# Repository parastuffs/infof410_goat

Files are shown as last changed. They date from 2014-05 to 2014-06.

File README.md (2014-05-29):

infof410_goat
=============

INFOF410 - Project GOAT

We should have a synchronization sent from the user and received by the
controller, but not the other way around.
Indeed, when the user crosses the first infrared, we want the controller
to take immediate action, hence the sync.
On the other hand, when the controller open the second door, the user
is not compelled to leave the SAS through it just yet. In this case,
we better have a boolean variable activated by the controller allowing
the user to get the frack out if he wishes.

>We want the environnement to be able to loose. So `E<> User.FAIL` should
be satisfied. But, with the cooperation of the controller, we
want `control: A[] not User.FAIL` to be satisfied as well, that is with 
the help of the controller, we
cannot loose the game.

The paragraph just above may be just bullshit. Indeed, the transition
to User.FAIL state is a controllable one. So no shit that with the help
of the controller, we will never take that transition!

The only solution here is to force the SAS model to send a sync signal
when the timer is out by adding a gard on SAS.handling_user state.

UppAal Tiga tips
----------------

* You can make several updates at the same time by seperating them with
commas.
* You can use logical operators in guards: || and &&.
* ~~We cannot take a transition with a sync signal if the corresponding
node is not in a state waiting for it.~~ So not true.

Current State
-------------

User:

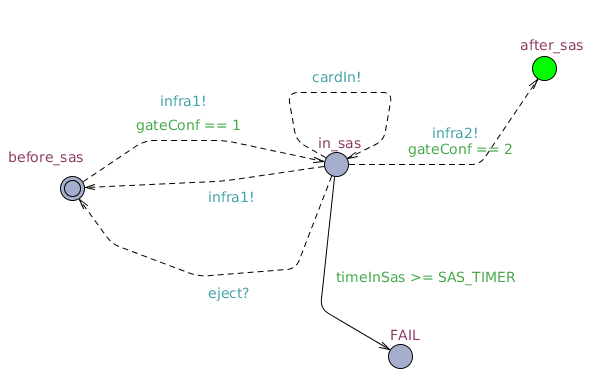
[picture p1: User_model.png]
User


SAS:

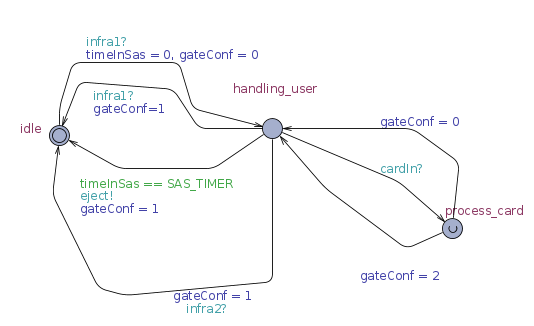
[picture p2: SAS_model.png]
SAS


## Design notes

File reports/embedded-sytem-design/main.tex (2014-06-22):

%%%%%%%%%%%%%%%%%%%%%%%%%%%%%%%%%%%%%%%%%
% Minimalist Book Title Page 
% LaTeX Template
% Version 1.0 (27/12/12)
%
% This template has been downloaded from:
% http://www.LaTeXTemplates.com
%
% Original author:
% Peter Wilson (herries.press@earthlink.net)
%
% License:
% CC BY-NC-SA 3.0 (http://creativecommons.org/licenses/by-nc-sa/3.0/)
% 
% Instructions for using this template:
% This title page compiles as is. If you wish to include this title page in 
% another document, you will need to copy everything before 
% \begin{document} into the preamble of your document. The title page is
% then included using \titleTH within your document.
%
%%%%%%%%%%%%%%%%%%%%%%%%%%%%%%%%%%%%%%%%%

%----------------------------------------------------------------------------------------
%	PACKAGES AND OTHER DOCUMENT CONFIGURATIONS
%----------------------------------------------------------------------------------------

%\title{Embedded Sytem Design: The GOAT}

\documentclass[10pt,a4paper]{article}

\usepackage[utf8]{inputenc}
\usepackage[T1]{fontenc}
\usepackage[svgnames]{xcolor} % Required to specify font color
\usepackage{mathpazo}
\usepackage{floatrow}
\usepackage{geometry}%réglages mise en page
\geometry{%
a4paper, % note : l'option a4paper tuait la marge supérieure.
body={170mm,250mm}, %
left=25mm,top=25mm,right=25mm, %
headheight=21mm,headsep=7mm,
marginparsep=4mm,
marginparwidth=20mm, %
footnotesep=50mm
}

\usepackage{graphicx}
\usepackage{float}
\usepackage{color}
\usepackage{amssymb}

%\usepackage[boxed]{algorithm2e}
\usepackage{array}
\usepackage{hyperref}
\usepackage{lscape}

%%% Pour colorier le code source C++/matlab
\usepackage{listings}
\usepackage{xcolor}
\usepackage[colorinlistoftodos]{todonotes}

\newcommand*{\course}{\fbox{INFO-F-410}} % Generic publisher logo

%----------------------------------------------------------------------------------------
%	TITLE PAGE
%----------------------------------------------------------------------------------------

\newcommand*{\titleTH}{\begingroup % Create the command for including the title page in the document
\raggedleft % Right-align all text
\vspace*{\baselineskip} % Whitespace at the top of the page

{\Large \textsc{Anthony Debruyn}}\\[0.01\textheight] % Author name
{\Large \textsc{Brian Delhaisse}}\\[0.01\textheight] % Author name
{\Large \textsc{Quentin Delhaye}}\\[0.167\textheight] % Author name

{\LARGE\bfseries Embedded Systems Design}\\[\baselineskip] % First part of the title, if it is unimportant consider making the font size smaller to accentuate the main title

{\textcolor{green}{\Huge The GOAT}}\\[\baselineskip] % Main title which draws the focus of the reader

{\Large \textit{The Gate Opener Actioned by Ticket}}\par % Tagline or further description

\vfill % Whitespace between the title block and the publisher

%\vspace*{30\baselineskip} % Whitespace at the bottom of the page

{\large \textsc{Gilles Geraerts} \course}\par % Publisher and logo

%\vspace*{5\baselineskip} % Whitespace at the bottom of the page
\endgroup}

%----------------------------------------------------------------------------------------
%	BLANK DOCUMENT
%----------------------------------------------------------------------------------------

%%%%%%%%%%%%%%%%%%%%%%%%%%%%%%%%%%%%%%%%%%%%%%%%%%%%%%%%%%%%%%%%%%%%%%%%
%%
%%    Environnement coloré pour écrire des codes.
%%
%%      Environnement :
%%       lstlisting
%%
%%      UTILISATION :
%%
%%         \lstset{language=c++}
%%         \lstset{commentstyle=\color{colComments}\textit}
%%         \begin{lstlisting}
%%             CODE
%%         \end{lstlisting}
%%
%%
%%%%%%%%%%%%%%%%%%%%%%%%%%%%%%%%%%%%%%%%%%%%%%%%%%%%%%%%%%%%%%%%%%%%%%%%

\definecolor{colKeys}{rgb}{0,0,1}  % couleurs des mots-clés propres au language
\definecolor{colIdentifier}{rgb}{0,0,0}  % couleurs des mots à identifier
\definecolor{colComments}{rgb}{0,0.6,0}  % couleurs des commentaires
\definecolor{colString}{rgb}{0.6,0.1,0.1}
%\lstset{}

%%%%%%%%%%%%%%%%%%%%%%%%%%%%%%%%%%%%%%%%%%%%%%%%%%%%%%%%%%%%%%%%%%%%%%%%%%%%%%%%%%%

\begin{document} 

\thispagestyle{empty}

\titleTH % This command includes the title page

\newpage

\tableofcontents
\newpage
%%%%%%%% Introduction %%%%%%%%%%
\section{Introduction}
For the course "Embedded Systems Design", we were asked to implement a system inspired from a subject in the course. We chose to use UppAal Tiga to design and create a strategy for a sas controlled by an Arduino Uno. This sas is composed of 2 doors actioned by servomotors. Infrared sensors are used to detect the person entering the sas. The opening of the second door of the sas is triggered by the scan of a valid card (rectangle with holes). Once someone is inside the sas, a timer is triggered to prevent the person to stay indefinitely inside. An alarm is activated once the timer is out.

%%%%%%%% The Model %%%%%%%%%%%%
\section{The Model}

In this section we will describe the physical properties that the system must satisfy, and make the link with the model.\\

First we want the system to always have at least one door closed. This is ensured by the 3 available configurations in the model: \emph{01} meaning door 1 open and door 2 closed, \emph{10} meaning the opposite, and \emph{00} meaning no door open.\\

Secondly, we want the back door (door 2) to open only if the user present one valid card having 2 holes in it.\\

The user also has to be ejected after some time if he does not show a valid card. This would prevent the user from staying indefinitely in the sas, blocking the other users. This is done by the timer in the model for the sas and the eject message. \\

The sas must detect the insertion of a card, even if it is not valid. This is modeled with the cardIn message in the UppAal Tiga systems.\\

An infrared sensor system has to detect the entry and exit of the user in order to react with the appropriate door configuration, and (de)activate the alarm. In the model, the infrared sensors are modeled with the infra1 \& infra2 signal.

The user must be able to escape the sas at any time. This is done with the infra1 sensor. If the user puts himself in front of the sensor, the front door opens to let him out.

The figures~\ref{userModel} and \ref{sasModel} represent these and the listings~\ref{globalDecl}, \ref{userDecl} and \ref{sasDecl} are their declarations.

A Typical run on the user side is as follows: The user begins in \texttt{before\_sas} and proceed into the sas by triggering the \texttt{infra1} signal if the first door is opened. He enters either with a valid or invalid card.
Once in the sas, he can present his card by triggering the \texttt{cardIn} signal.
At any moment, if the second door is opened, he can leave through it, or leave through the first door by triggering the signal \texttt{infra1}.
If the global clock \texttt{timeInSas} exceeds \texttt{SAS\_TIMER}, he can go to the \texttt{FAIL} state, and when receiving the \texttt{eject} signal, he will leave the sas.

A typical run on the sas side is as follows: From the \texttt{idle} state, uppon \texttt{infra1} signal, the sas resets the clock \texttt{timeInSas} and closes the first door. 
The sas is then handling a user. 
When a detects that a card is entered, it either opens the second door if the card is correct but keep both closed if the card is invalid.
If it receives the signal \texttt{infra1}, it means that the user is standing in front of the first sensor and wants to leave, hence the sas opens the first door.
Whenever the \texttt{timeInSas} clock reaches the \texttt{SAS\_TIMER}, the sas immediatly triggers the \texttt{eject} signal, willing to make the user leave the bloody sas.

\begin{figure}[!h]
	\centering
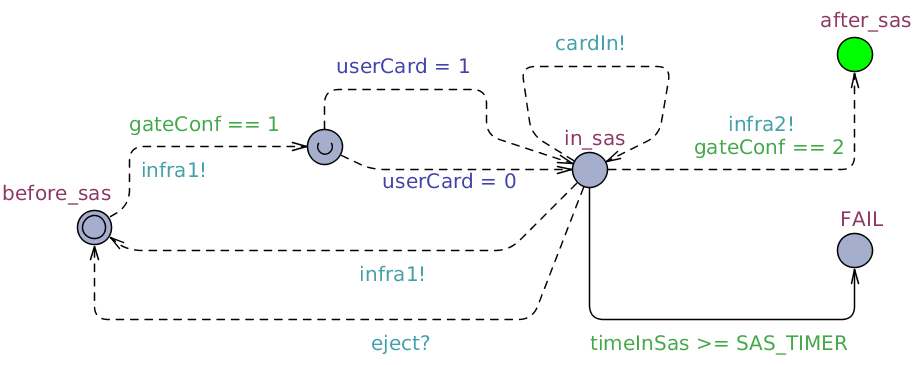
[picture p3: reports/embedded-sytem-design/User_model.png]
    
    \caption{The user model}
    \label{userModel}
\end{figure}

\begin{figure}[!h]
	\centering
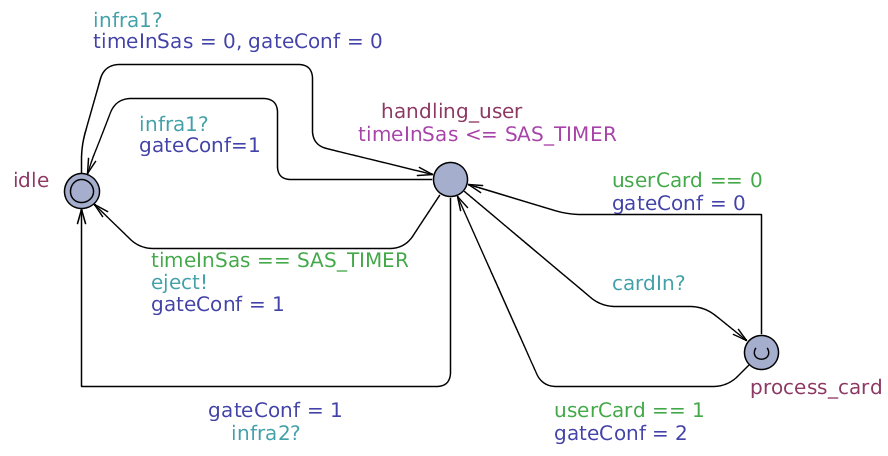
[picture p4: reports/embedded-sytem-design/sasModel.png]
    
    \caption{The sas model}
    \label{sasModel}
\end{figure}

\lstset{language=c++}
\lstset{commentstyle=\color{colComments}\textit,
%float=hbp,%
basicstyle=\ttfamily\small, %
identifierstyle=\color{colIdentifier}, %
keywordstyle=\color{colKeys}, %
stringstyle=\color{colString}, %
commentstyle=\color{colComments}, %
columns=flexible, %
tabsize=2, %
%frame=trBL, %
%frameround=tttt, %
extendedchars=true, %
showspaces=false, %
showstringspaces=false, %
numbers=left, %
numberstyle=\tiny, %
breaklines=true, %
breakautoindent=true, %
captionpos=b,%
%xrightmargin=-0.6cm, %
%xleftmargin=-0.6cm}
}
\begin{lstlisting}[caption=Global declarations of the systems., label=globalDecl]
chan infra1, infra2, cardIn, eject;
clock timeInSas;
const int SAS_TIMER = 10;
int gateConf = 1;
int userCard;
\end{lstlisting}
\begin{lstlisting}[caption=Declarations of the user model., label=userDecl]
clock x;
\end{lstlisting}
\begin{lstlisting}[caption=Declarations of the sas model., label=sasDecl]
clock x;
\end{lstlisting}

%%%%%%%%%%%%%%%%%%%%%%%%%%%%%%%%%
\section{The Strategy}
%%%%%%%%%%%%%%%%%%%%%%%%%%%%%%%%%
\subsection{Winning conditions}

\begin{description}
	%\item[\texttt{A<> not(User.FAIL)}] ~\\
    %	The user will never end up in FAIL.
        
    \item[\texttt{A[] not(User.in\_sas and User2.in\_sas)}] ~\\     
    Both users are never in the sas at the same time.
    Both models are exactly the same. The managment of a request token and a users queue will be implemented for the Formal Verification project.
    
    %\item[\texttt{A[] not deadlock}] ~\\
    
    \item[\texttt{E<> User.after\_sas}] ~\\
    	It is possible for the user to reach the other side of the sas. He won't succeed on every try, but if he wants to, he will.

    \item[\texttt{A[] not (User.FAIL)}] ~\\
    	We want to verify if the user will always avoid the FAIL state.
        At the instant \texttt{timeInSas} = \texttt{SAS\_TIMER} the system has two choice: either take \texttt{Sas.handling\_user} to \texttt{Sas.idle}, or \texttt{User.in\_sas} to \texttt{User.before\_sas}.
        The FAIL state is thus reachable and the test is expected to fail.
    
    \item[\texttt{control: A[] not(User.FAIL or User2.FAIL)}] ~\\
    Here, we play in a controller game.
    Having the controller collaboration, when the system is given the opportunity to either win or lose, well, it chooses to win.
    This condition is there to enforce the limited time in sas property.
    
    Please bear in mind here that we suppose that the \texttt{eject!} signal sent by the \texttt{Sas} has force of law.
    Hence, we know that when the controller is trying to comply with a winning condition, our physical system will be able to overcome the quite strong hypothesis made by the simulation tool stating that the environnement is always able to act faster than the controller.
    This liberty is represented by the controllable edge between \texttt{User.in\_sas} and \texttt{user.FAIL}.
\end{description}

We may also want to verify that if the user enters the sas with an invalid card, he will not make it to the other side, but if he has a valid card, he may.
This may be expressed as follows:
\begin{small}
\begin{verbatim}
	A[] ( ( (userCard == 0 && User.in_sas) imply A<> User.before_sas ) 
	&& ( (userCard == 1 && User.in_sas) imply E<> User.after_sas ) )
\end{verbatim}
\end{small}

Sadly, the syntax analyzer of UppAal does not accept a quantifier after the keyword \texttt{imply} and the above condition is not verifiable through its tools.\\

Finally, one could think that a suitable strategy for the sas to avoid the user to enter the \texttt{FAIL} state would simply be to never open the first door and let users in.
However, the model construction is such that the first door is always open when the sas is not occupied.
The only way to close the first door is for a user to enter the sas by triggering the \texttt{infra1} signal.

\subsection{Generated strategy}
The following strategy has been generated using a system with only one user for readability purposes.

\begin{verbatim}
Verifying property 5 at line 28
 -- Property is satisfied.
$v_gameInfoPlayInitial state:
( User.before_sas Sas.idle ) gateConf=1 
(timeInSas==User.x && User.x==Sas.x && Sas.x==0)

Strategy to avoid losing:

State: ( User.after_sas Sas.idle ) gateConf=1 
While you are in	true, wait.

State: ( User.before_sas Sas.idle ) gateConf=1 
While you are in	true, wait.

State: ( User.in_sas Sas.handling_user ) gateConf=2 
While you are in	(timeInSas<=10), wait.

State: ( User.in_sas Sas.process_card ) gateConf=0 
When you are in (timeInSas<=10), 
	take transition Sas.process_card->Sas.handling_user { 1, tau, gateConf := 2 }

State: ( User.in_sas Sas.process_card ) gateConf=2 
When you are in (timeInSas<=10), 
	take transition Sas.process_card->Sas.handling_user { 1, tau, gateConf := 2 }

State: ( User.in_sas Sas.handling_user ) gateConf=0 
While you are in	(timeInSas<=10), wait.
\end{verbatim}

The implementation code is presented in appendix~\ref{ap:code}. Each of those states were implemented using \texttt{if-then-else} statements decorated with all kind of computation that were hidden behind abstractions in the models.

\section{Physical Implementation}
\subsection{Parts list}
For our prototype, we used:
\begin{itemize}
	\item a microcontroller: Arduino UNO.
	\item 5 resistances (220$\Omega$).
    \item 3 leds (1red, 1yellow, 1green).
    \item 2 analog servo motors (FS5103B).
    \item 2 infrared proximity sensors short range.
    \item 2 photoresistors.
    \item 1 micro switch (DM3).
    \item 1 buzzer.
    \item 1 battery pack holder for 4x AA batteries + the 4xAA batteries.
    \item jump wires.
    \item 3 half-size protoboards.
\end{itemize}

\subsection{Electronic schematic}

\begin{figure}[!h]
	\centering
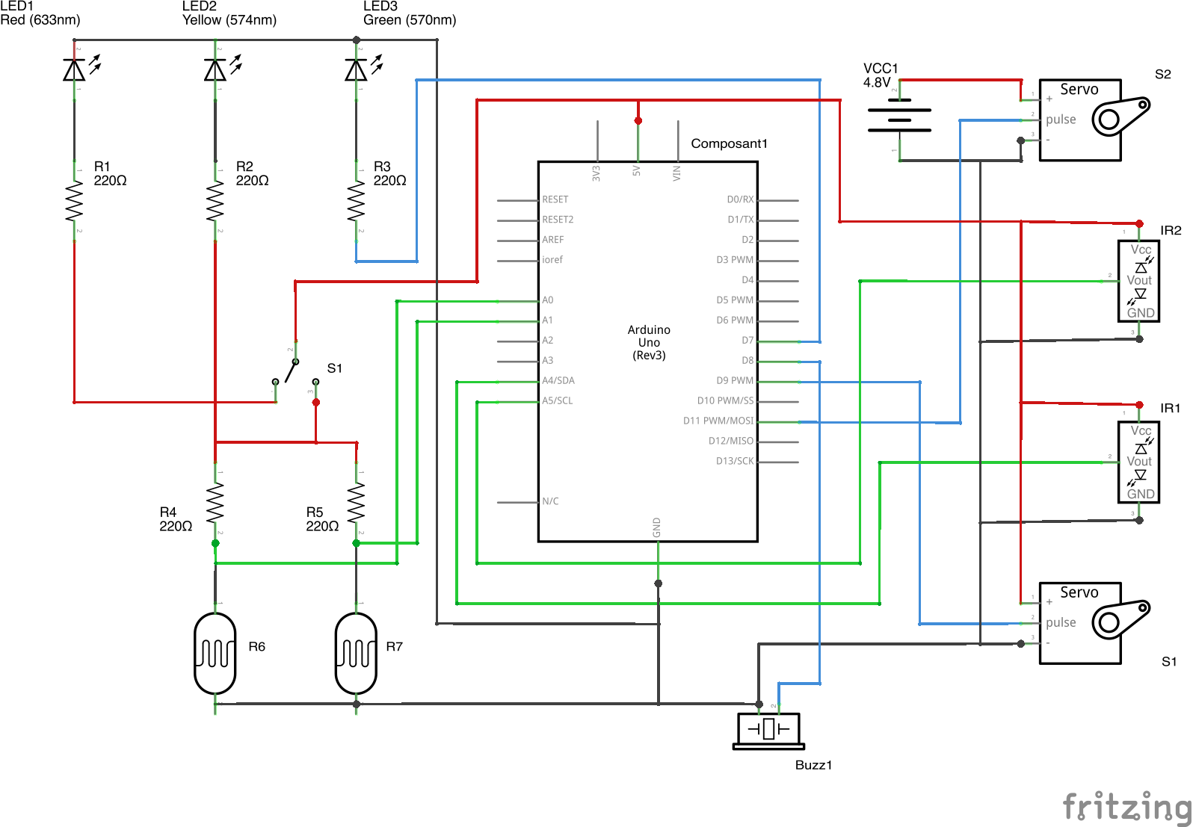
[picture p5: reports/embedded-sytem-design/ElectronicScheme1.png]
    
    \caption{Electrical diagram (modeled with Fritzing). Legend: \textcolor{red}{red wires} are connected to the positive terminal (of the arduino or the external battery), black wires are connected to the ground, \textcolor{green}{green wires} connect the electrical components to the analog input pins, and the \textcolor{blue}{blue wires} connect electrical components to digital output pins.}
    \label{elecScheme}
\end{figure}

Once the arduino is connected to a computer or to a battery, the positive terminal of the arduino supplies a tension of 5V to the electrical system, which can be seen on the figure \ref{elecScheme}. Because the servo motors drain a lot of current, another external battery was needed to supply enough current for both servo motors. Thus, an external battery has been connected to one of the servo. To avoid any other problems, we connected the ground of this one to the same ground as the arduino.

The resistors in front of each led are there so that the leds don't overdrive and burn out. The red led is always on until a card is inserted into the system. The card will push on the lever of the micro switch leading to the yellow led to turn on, and to the current to flow into the photoresistors.

The 2 resistors R4 and R5 with the photoresistors R6 and R7 form respectively a voltage divider. The voltage measured differs with the intensity of the light, that is, brighter the light is smaller the resistance of the photoresistor is. The resulting tension of those dividers are measured on the analog input pins A0 and A1 of the arduino. If the tension of each photoresistor is between a certain value, then the microcontroller is programmed to turn on the green led, and activate the 2nd servo motor (S2) in order to open the last door of the sas. 

If the user stays too long in the sas, the arduino can also trigger an alarm with the buzzer.

The two infrared proximity sensors IR1 and IR2 are there to detect if an object/person has entered or leaved the sas, they are respectively connected to the analog input pins A4 and A5. Based on the value measured, the microcontroller will activate one of the servo motors to close one of the gates, or to stop the buzzer.

\subsection{Electronic circuit}
On the real circuit, we used three breadboards because of the jump wires length that were too short. The two leftern protoboards on the figure \ref{circuit} are perpendicular to each other, in order for the card to be able to push on the lever of the micro switch, and for the photoresistors to be perpendicular to the card.

\begin{figure}[!h]
	\centering
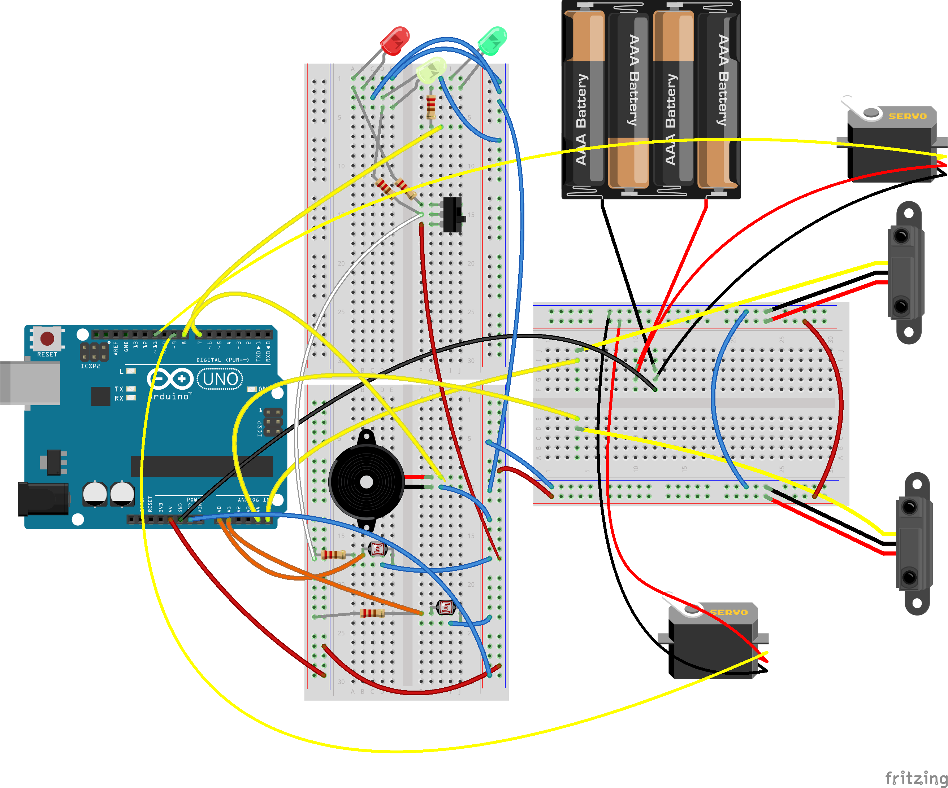
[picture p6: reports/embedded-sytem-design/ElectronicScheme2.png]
    
    \caption{The Circuit (modeled with Fritzing).}
    \label{circuit}
\end{figure}

\subsection{The structure}
The sas was build using Lego bricks, and the doors are in carton and connected to the servomotors with paperclips. We used cardboard to create some cards. A valid card has a hole in front of each photoresistor, so that the light can pass through it and be detected by the photoresistors. The final physical prototype can be found on the figure \ref{finalPrototype}.

%On figure \ref{inside}, the reader can view the inside of the sas. Here the first door is open, and the user is waiting.

\begin{figure}[!h]
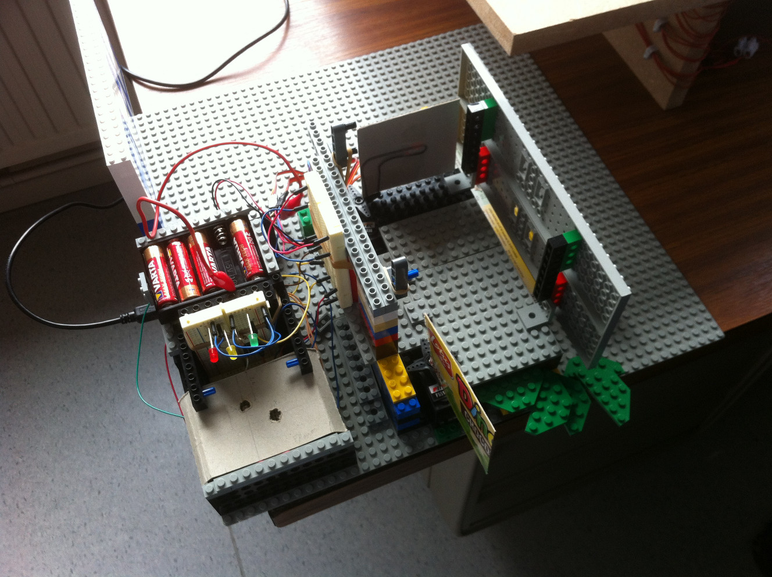
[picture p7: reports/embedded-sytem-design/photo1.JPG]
	
    \caption{Final prototype}
    \label{finalPrototype}
\end{figure}

\section{Future work}
Since we only use one infrared sensor at each door, we do not know the direction of the passing user. This causes problems in several situations:

\begin{itemize}
	\item If the user stays too long in the sas and the alarm activate, another user can enter in the sas. The alarm then stops. Now a third user can enter, and the front door closes. If one of the 2 users already in the sas puts something in front of the sensor, the front door closes as well. Thus any number of people enter the sas and go to the other side with one valid card.
    
    \item The same infrared problem occurs on the other side. If one user enters the sas from the back door when it is open, after the user has shown a valid card, the sas closes the second door. There are then 2 users in the sas, and the front door opens again, letting the second user escape.
	
\end{itemize}

These two problems could be resolved by using 2 more sensors to detect the direction of the passing user. Anoher solution could be to consider that the sas has only room for one person only.

%%%%%%%%%%%%%
\section{Conclusion}
%%%%%%%%%%%%%
This project has given us the opportunity to understand how we design embedded systems, by using specific tools to verify that a system respect some given proprieties. It was a rich experience to do the different parts of a project: the design of the model, the production of the code from the generated strategies, and the physical implementation so that we can see that our model really works in the real world.

\newpage

\appendix

\section{Arduino Code}\label{ap:code}
As mentionned above, the following code has been produced based on the generated strategies.\\

\lstset{language=c++}
\lstset{commentstyle=\color{colComments}\textit,
float=hbp,%
basicstyle=\ttfamily\small, %
identifierstyle=\color{colIdentifier}, %
keywordstyle=\color{colKeys}, %
stringstyle=\color{colString}, %
columns=flexible, %
tabsize=2, %
frame=trBL, %
frameround=tttt, %
extendedchars=true, %
showspaces=false, %
showstringspaces=false, %
numbers=left, %
numberstyle=\tiny, %
breaklines=true, %
breakautoindent=true, %
captionpos=b,%
xrightmargin=-0.6cm, %
xleftmargin=-0.6cm}
\begin{lstlisting}
#include <Servo.h> 

Servo servo1;  // create servo object to control a servo 
Servo servo2; 

int pos1;    // variable to store the servo position 
int pos2;

const int ledPin = 7;      // the number of the LED pin
const int buz = 8;
int buzCount = 0;

int gateConf;
unsigned long startTime;
const int SAS_TIMER = 5000;
boolean userIn;

#define but1 A4
#define but2 A5
#define infra1 (analogRead(A4) > 550)
int infra1Count;
#define infra2 (analogRead(A5) > 500)
int infra2Count;
#define cardIn (analogRead(A0) > 0 && analogRead(A1) > 0)

void setup() 
{ 
  pos1 = 0;//Opened
  pos2 = 90;//Closed
  servo1.attach(9);  // attaches the servo on pin 9 to the servo object 
  servo2.attach(11);
  Serial.begin(9600);
  servo1.write(pos1);
  delay(150);
  servo2.write(pos2);
  delay(150);
  
  // set the digital pin as output:
  pinMode(ledPin, OUTPUT);
  pinMode(buz, OUTPUT);
  
  gateConf = 1;
  userIn = false;
  infra1Count = 0;
  infra2Count = 0;
} 

void changeGateConf(int conf)
{
  gateConf = conf;
  switch (conf) {
    case 0:
      //from 1
      //Close gate 1
      for(pos1; pos1 < 90; pos1 += 1) {
        servo1.write(pos1);
        delay(15);
      }
      //gate 2 already closed
      break;
      
    case 1:
      //Open gate 1 : 0->90
      //Close gate 2 : 180->90
      for(pos2; pos2 > 90; pos2 -= 1) {
        servo2.write(pos2);
        delay(15);
      }
      for(pos1; pos1 > 0; pos1 -= 1) { 
        servo1.write(pos1);
        delay(15);
      }
      break;
      
    case 2:
      //gateConf = 2
      //Close gate 1: 90->0
      //Open gate 2: 0->90
      
      for(pos1; pos1 < 90; pos1 += 1) {  
        servo1.write(pos1);
        delay(15);
      }
      for(pos2; pos2 < 180; pos2  += 1) {
        servo2.write(pos2);
        delay(15);
      }
      break;
      
    default:
       break;
  }  
}

boolean processCard()
{
  int sensorValue = analogRead(A0);
  int sensorValue2 = analogRead(A1);
  if(sensorValue>200 && sensorValue<400 && sensorValue2>200 && sensorValue2<400)
    return true;
  else
    return false;
}

void alarm(boolean on)
{
  if(on) {
    int i;
    if(buzCount < 9) {
      for(i=0; i<10; i++) {
        digitalWrite(buz, HIGH);
        delay(3);//Shorter delay = higher pitch
        digitalWrite(buz, LOW);
        delay(3);
      }
      buzCount ++;
    } else {
      for(i=0; i<10; i++) {
        digitalWrite(buz, HIGH);
        delay(18);
        digitalWrite(buz, LOW);
        delay(18);
      }
      buzCount = 0;
    }
  }
}

void eject()
{
  digitalWrite(ledPin, LOW);
  changeGateConf(1);
  Serial.println("GET OUT. NOW");
  while(!infra1) {
    Serial.println("GET OUT. NOW");
    alarm(true);
  }
  while(infra1);
  alarm(false);
} 

void loop() 
{ 
  //infra1!
  if(infra1 && gateConf == 1 && !userIn) {
    userIn = true;
    Serial.print("userIn: ");
    Serial.println(userIn);
    gateConf = 0;
    changeGateConf(gateConf);
    startTime = millis();
  }
  
  if(infra2 && gateConf == 2) {
    gateConf = 1;
    userIn = false;
    digitalWrite(ledPin, LOW);
    changeGateConf(gateConf);
  }
  
  if(gateConf == 0 || gateConf == 2) {
    if((millis() - startTime) <= SAS_TIMER) {
      if(cardIn) {
        if(processCard()) {
          digitalWrite(ledPin, HIGH);
          gateConf = 2;
          changeGateConf(gateConf);
        }
        else
          digitalWrite(ledPin, LOW);
      }
      else
        digitalWrite(ledPin, LOW);
    }
    else {
      eject();
      userIn = false;
    }
  } 

  delay(50);   // delay in between reads for stability
} 
\end{lstlisting}

\end{document}

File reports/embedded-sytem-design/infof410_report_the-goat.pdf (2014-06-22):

ANTHONY DEBRUYN
BRIAN DELHAISSE
QUENTIN DELHAYE

# Embedded Systems Design

# The GOAT

## The Gate Opener Actioned by Ticket

### GILLES GERAERTS INFO-F-410

## Contents

1 Introduction | 3
2 The Model | 3
3 The Strategy | 4
4 Physical Implementation | 6
5 Future work | 8
6 Conclusion | 8
A Arduino Code | 9

## 1 Introduction

For the course "Embedded Systems Design", we were asked to implement a system inspired from a subject in the course. We chose to use UppAal Tiga to design and create a strategy for a sas controlled by an Arduino Uno. This sas is composed of 2 doors actioned by servomotors. Infrared sensors are used to detect the person entering the sas. The opening of the second door of the sas is triggered by the scan of a valid card (rectangle with holes). Once someone is inside the sas, a timer is triggered to prevent the person to stay indefinitely inside. An alarm is activated once the timer is out.

## 2 The Model

In this section we will describe the physical properties that the system must satisfy, and make the link with the model.

First we want the system to always have at least one door closed. This is ensured by the 3 available configurations in the model: 01 meaning door 1 open and door 2 closed, 10 meaning the opposite, and 00 meaning no door open.

Secondly, we want the back door (door 2) to open only if the user present one valid card having 2 holes in it.

The user also has to be ejected after some time if he does not show a valid card. This would prevent the user from staying indefinitely in the sas, blocking the other users. This is done by the timer in the model for the sas and the eject message.

The sas must detect the insertion of a card, even if it is not valid. This is modeled with the cardIn message in the UppAal Tiga systems.

An infrared sensor system has to detect the entry and exit of the user in order to react with the ap-propriate door configuration, and (de)activate the alarm. In the model, the infrared sensors are modeled with the infra1 & infra2 signal.
The user must be able to escape the sas at any time. This is done with the infra1 sensor. If the user puts himself in front of the sensor, the front door opens to let him out.
The figures 1 and 2 represent these and the listings 1, 2 and 3 are their declarations.
A Typical run on the user side is as follows: The user begins in before_sas and proceed into the sas by triggering the infra1 signal if the first door is opened. He enters either with a valid or invalid card. Once in the sas, he can present his card by triggering the cardIn signal. At any moment, if the second door is opened, he can leave through it, or leave through the first door by triggering the signal infra1. If the global clock timeInSas exceeds SAS_TIMER, he can go to the FAIL state, and when receiving the eject signal, he will leave the sas.
A typical run on the sas side is as follows: From the idle state, uppon infra1 signal, the sas resets the clock timeInSas and closes the first door. The sas is then handling a user. When a detects that a card is entered, it either opens the second door if the card is correct but keep both closed if the card is invalid. If it receives the signal infra1, it means that the user is standing in front of the first sensor and wants to leave, hence the sas opens the first door. Whenever the timeInSas clock reaches the SAS_TIMER, the sas immediatly triggers the eject signal, willing to make the user leave the bloody sas.
1 | chan infra1, infra2, cardIn, eject;
2 | clock timeInSas;
3 | const int SAS_TIMER = 10;
4 | int gateConf = 1;
5 | int userCard;
Listing 1: Global declarations of the systems.

1 clock x;
Listing 2: Declarations of the user model.

1 clock x;
Listing 3: Declarations of the sas model.

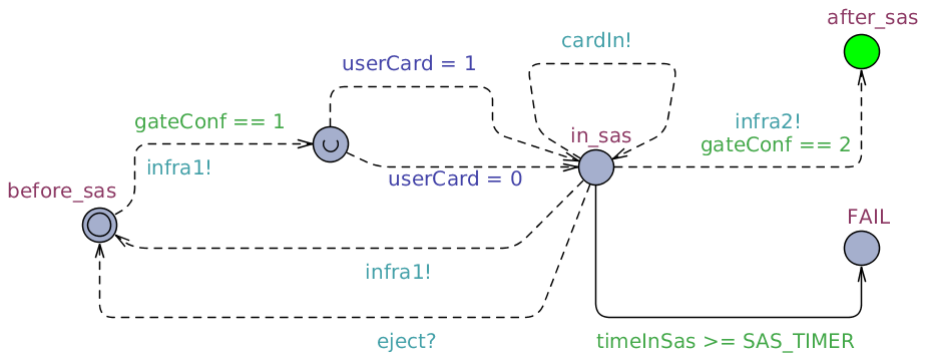
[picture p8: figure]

Figure 1: The user model

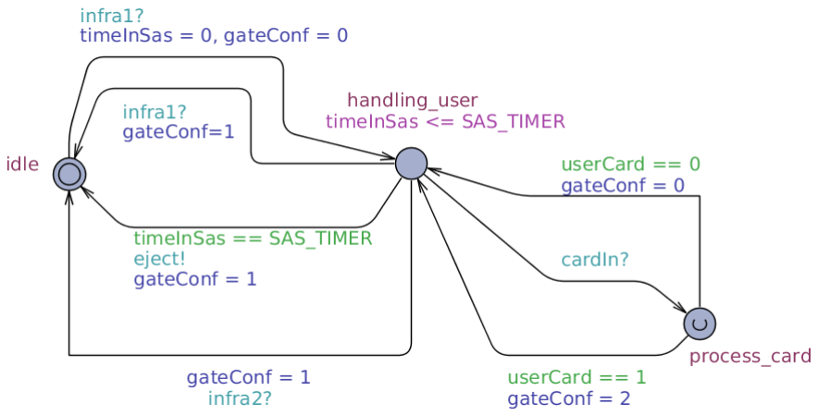
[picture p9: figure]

Figure 2: The sas model

## 3 The Strategy

### 3.1 Winning conditions

A[] not(User.in_sas and User2.in_sas)
Both users are never in the sas at the same time. Both models are exactly the same. The managment of a request token and a users queue will be implemented for the Formal Verification project.

E<> User.after_sas
It is possible for the user to reach the other side of the sas. He won’t succeed on every try, but if he wants to, he will.

A[] not (User.FAIL)
We want to verify if the user will always avoid the FAIL state. At the instant timeInSas = SAS_TIMER
the system has two choice: either take Sas.handling_user to Sas.idle, or User.in_sas to User.before_sas. The FAIL state is thus reachable and the test is expected to fail.

control: A[] not(User.FAIL or User2.FAIL)
Here, we play in a controller game. Having the controller collaboration, when the system is given the opportunity to either win or lose, well, it chooses to win. This condition is there to enforce the limited time in sas property.
Please bear in mind here that we suppose that the eject! signal sent by the Sas has force of law. Hence, we know that when the controller is trying to comply with a winning condition, our physical system will be able to overcome the quite strong hypothesis made by the simulation tool stating that the environnement is always able to act faster than the controller. This liberty is represented by the controllable edge between User.in_sas and user.FAIL.

We may also want to verify that if the user enters the sas with an invalid card, he will not make it to the other side, but if he has a valid card, he may. This may be expressed as follows:

A[] ( ( (userCard == 0 && User.in_sas) imply A<> User.before_sas )
&& ( (userCard == 1 && User.in_sas) imply E<> User.after_sas ) )

Sadly, the syntax analyzer of UppAal does not accept a quantifier after the keyword imply and the above condition is not verifiable through its tools.

Finally, one could think that a suitable strategy for the sas to avoid the user to enter the FAIL state would simply be to never open the first door and let users in. However, the model construction is such that the first door is always open when the sas is not occupied. The only way to close the first door is for a user to enter the sas by triggering the infra1 signal.

### 3.2 Generated strategy

The following strategy has been generated using a system with only one user for readability purposes.

Verifying property 5 at line 28
-- Property is satisfied.
$v_gameInfoPlayInitial state:
( User.before_sas Sas.idle ) gateConf=1 (timeInSas==User.x && User.x==Sas.x && Sas.x==0)

Strategy to avoid losing:

State: ( User.after_sas Sas.idle ) gateConf=1 While you are in true, wait.

State: ( User.before_sas Sas.idle ) gateConf=1 While you are in true, wait.

State: ( User.in_sas Sas.handling_user ) gateConf=2 While you are in (timeInSas<=10), wait.

State: ( User.in_sas Sas.process_card ) gateConf=0
When you are in (timeInSas<=10),
take transition Sas.process_card->Sas.handling_user { 1, tau, gateConf := 2 }

State: ( User.in_sas Sas.process_card ) gateConf=2
When you are in (timeInSas<=10),
take transition Sas.process_card->Sas.handling_user { 1, tau, gateConf := 2 }

State: ( User.in_sas Sas.handling_user ) gateConf=0
While you are in (timeInSas<=10), wait.

The implementation code is presented in appendix A. Each of those states were implemented using if-then-else statements decorated with all kind of computation that were hidden behind abstractions in the models.

## 4 Physical Implementation

### 4.1 Parts list

For our prototype, we used:

- a microcontroller: Arduino UNO.
- 5 resistances (220Ω).
- 3 leds (1red, 1yellow, 1green).
- 2 analog servo motors (FS5103B).
- 2 infrared proximity sensors short range.
- 2 photoresistors.
- 1 micro switch (DM3).
- 1 buzzer.
- 1 battery pack holder for 4x AA batteries + the 4xAA batteries.
- jump wires.
- 3 half-size protoboards.

### 4.2 Electronic schematic

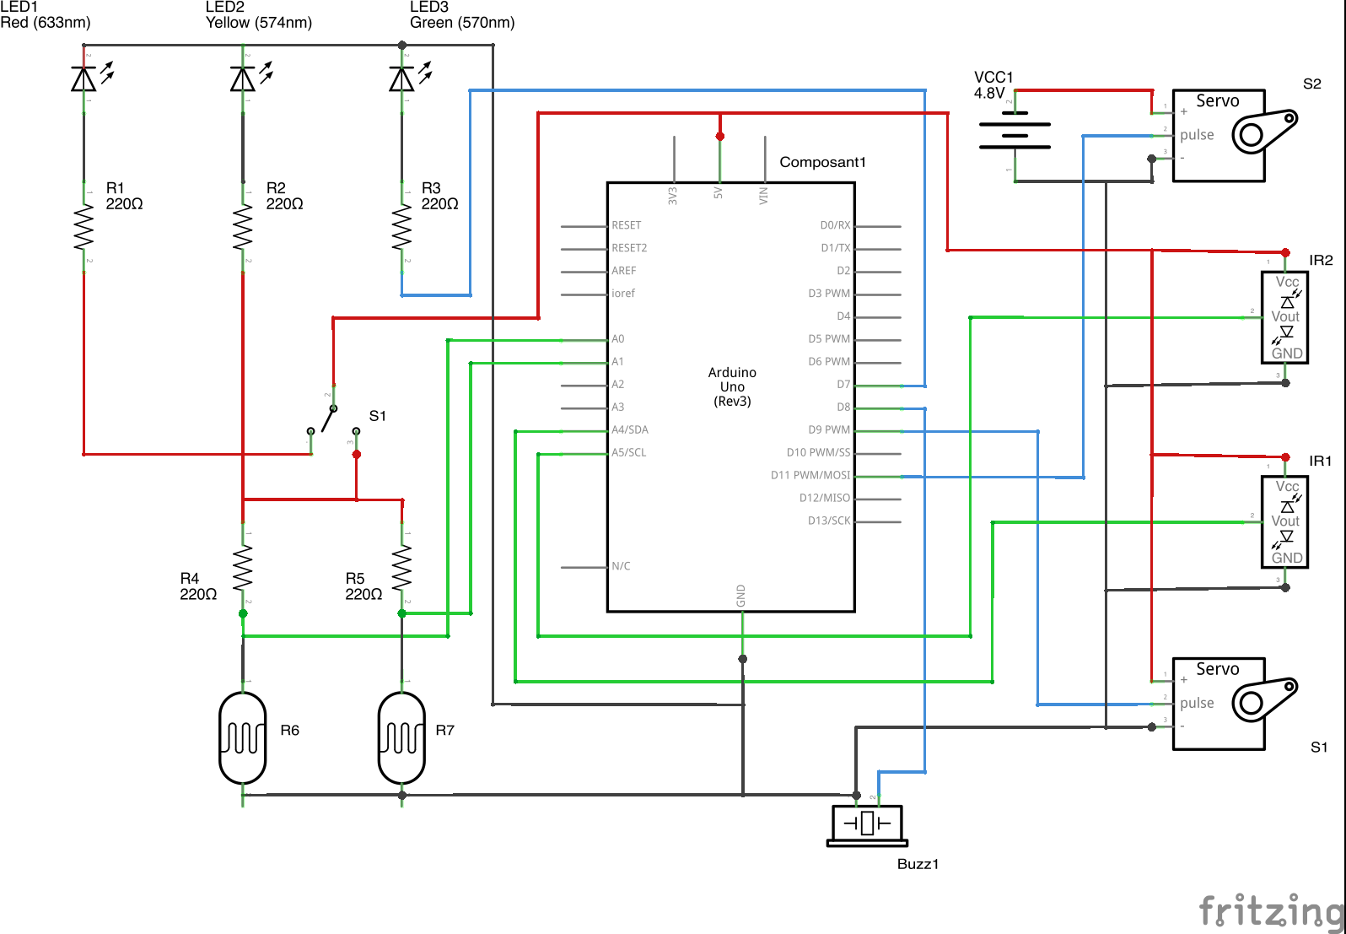
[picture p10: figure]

Figure 3: Electrical diagram (modeled with Fritzing). Legend: red wires are connected to the positive terminal (of the arduino or the external battery), black wires are connected to the ground, green wires connect the electrical components to the analog input pins, and the blue wires connect electrical components to digital output pins.

Once the arduino is connected to a computer or to a battery, the positive terminal of the arduino supplies a tension of 5V to the electrical system, which can be seen on the figure 3. Because the servo motors drain a lot of current, another external battery was needed to supply enough current for both servo motors. Thus, an external battery has been connected to one of the servo. To avoid any other problems, we connected the ground of this one to the same ground as the arduino.
The resistors in front of each led are there so that the leds don’t overdrive and burn out. The red led is always on until a card is inserted into the system. The card will push on the lever of the micro switch leading to the yellow led to turn on, and to the current to flow into the photoresistors.
The 2 resistors R4 and R5 with the photoresistors R6 and R7 form respectively a voltage divider. The voltage measured differs with the intensity of the light, that is, brighter the light is smaller the resistance of the photoresistor is. The resulting tension of those dividers are measured on the analog input pins A0 and A1 of the arduino. If the tension of each photoresistor is between a certain value, then the microcontroller is programmed to turn on the green led, and activate the 2nd servo motor (S2) in order to open the last door of the sas.
If the user stays too long in the sas, the arduino can also trigger an alarm with the buzzer.
The two infrared proximity sensors IR1 and IR2 are there to detect if an object/person has entered or leaved the sas, they are respectively connected to the analog input pins A4 and A5. Based on the value measured, the microcontroller will activate one of the servo motors to close one of the gates, or to stop the buzzer.

### 4.3 Electronic circuit

On the real circuit, we used three breadboards because of the jump wires length that were too short. The two leftern protoboards on the figure 4 are perpendicular to each other, in order for the card to be able to push on the lever of the micro switch, and for the photoresistors to be perpendicular to the card.


Figure 4: The Circuit (modeled with Fritzing).

### 4.4 The structure

The sas was build using Lego bricks, and the doors are in carton and connected to the servomotors with paperclips. We used cardboard to create some cards. A valid card has a hole in front of each photoresistor, so that the light can pass through it and be detected by the photoresistors. The final physical prototype can be found on the figure 5.


Figure 5: Final prototype

## 5 Future work

Since we only use one infrared sensor at each door, we do not know the direction of the passing user. This causes problems in several situations:

- If the user stays too long in the sas and the alarm activate, another user can enter in the sas. The alarm then stops. Now a third user can enter, and the front door closes. If one of the 2 users already in the sas puts something in front of the sensor, the front door closes as well. Thus any number of people enter the sas and go to the other side with one valid card.
- The same infrared problem occurs on the other side. If one user enters the sas from the back door when it is open, after the user has shown a valid card, the sas closes the second door. There are then 2 users in the sas, and the front door opens again, letting the second user escape.

These two problems could be resolved by using 2 more sensors to detect the direction of the passing user. Anoher solution could be to consider that the sas has only room for one person only.

## 6 Conclusion

This project has given us the opportunity to understand how we design embedded systems, by using specific tools to verify that a system respect some given proprieties. It was a rich experience to do the different parts of a project: the design of the model, the production of the code from the generated strategies, and the physical implementation so that we can see that our model really works in the real world.

## A Arduino Code

As mentionned above, the following code has been produced based on the generated strategies.
✞ | ☎

#include <Servo.h>

Servo servo1; // create servo object to control a servo Servo servo2;

6 | int pos1; | // variable to store the servo position
int pos2;
9 | const int ledPin = 7; | // the number of the LED pin
const int buz = 8;
int buzCount = 0;

int gateConf;
unsigned long startTime;
const int SAS_TIMER = 5000; boolean userIn;

#define but1 A4

#define but2 A5

#define infra1 (analogRead(A4) > 550) int infra1Count;

#define infra2 (analogRead(A5) > 500)

int infra2Count;
#define cardIn (analogRead(A0) > 0 && analogRead(A1) > 0)

void setup()

{
pos1 = 0;//Opened
pos2 = 90;//Closed
servo1.attach(9); // attaches the servo on pin 9 to the servo object servo2.attach(11);
Serial.begin(9600);
servo1.write(pos1);
delay(150);
servo2.write(pos2);
delay(150);

// set the digital pin as output: pinMode(ledPin, OUTPUT);
pinMode(buz, OUTPUT);

gateConf = 1;
userIn = false;
infra1Count = 0;
infra2Count = 0;

}

void changeGateConf(int conf)

{
gateConf = conf;
switch (conf) {
case 0:
//from 1
//Close gate 1
for(pos1; pos1 < 90; pos1 += 1) { servo1.write(pos1);
delay(15);

}
//gate 2 already closed
break;

61
62 | case 1:
63 | //Open gate 1 : 0->90
64 | //Close gate 2 : 180->90
65 | for(pos2; pos2 > 90; pos2 -= 1) {
66 | servo2.write(pos2);
67 | delay(15);
68 | }
69 | for(pos1; pos1 > 0; pos1 -= 1) {
70 | servo1.write(pos1);
71 | delay(15);
72 | }
73 | break;

74
75 | case 2:
76 | //gateConf = 2
77 | //Close gate 1: 90->0
78 | //Open gate 2: 0->90

79
80 | for(pos1; pos1 < 90; pos1 += 1) {
81 | servo1.write(pos1);
82 | delay(15);
83 | }
84 | for(pos2; pos2 < 180; pos2 += 1) {
85 | servo2.write(pos2);
86 | delay(15);
87 | }
88 | break;

89
90 | default:
91 | break;
92 | }
93 | }

94
95 | boolean processCard()
96 | {
97 | int sensorValue = analogRead(A0);
98 | int sensorValue2 = analogRead(A1);
99 | if(sensorValue>200 && sensorValue<400 && sensorValue2>200 && sensorValue2<400)
100 | return true;
101 | else
102 | return false;
103 | }

104
105 | void alarm(boolean on)
106 | {
107 | if(on) {
108 | int i;
109 | if(buzCount < 9) {
110 | for(i=0; i<10; i++) {
111 | digitalWrite(buz, HIGH);
112 | delay(3);//Shorter delay = higher pitch
113 | digitalWrite(buz, LOW);
114 | delay(3);
115 | }
116 | buzCount ++;
117 | } else {
118 | for(i=0; i<10; i++) {
119 | digitalWrite(buz, HIGH);
120 | delay(18);
121 | digitalWrite(buz, LOW);
122 | delay(18);
123 | }
124 | buzCount = 0;

125

}

126

}

127

}

128
129 | void eject()
130 | {
131 | digitalWrite (ledPin , LOW);
132 | changeGateConf(1);
133 | Serial .println ( "GET OUT . NOW ");
134 | while(!infra1) {
135 | Serial .println ( "GET OUT . NOW ");
136 | alarm (true);
137 | }
138 | while (infra1);
139 | alarm (false);
140 | }

141
142 | void loop()
143 | {
144 | //infra1 !
145 | if (infra1 && gateConf == 1 && !userIn) {
146 | userIn = true ;
147 | Serial .print ( "userIn : ");
148 | Serial .println (userIn);
149 | gateConf = 0;
150 | changeGateConf (gateConf);
151 | startTime = millis();
152 | }

153
154 | if (infra2 && gateConf == 2) {
155 | gateConf = 1;
156 | userIn = false ;
157 | digitalWrite (ledPin , LOW);
158 | changeGateConf (gateConf);
159 | }

160
161 | if (gateConf == 0 || gateConf == 2) {
162 | if((millis() - startTime) <= SAS_TIMER) {
163 | if (cardIn) {
164 | if (processCard()) {
165 | digitalWrite (ledPin , HIGH);
166 | gateConf = 2;
167 | changeGateConf (gateConf);
168 | }
169 | else
170 | digitalWrite (ledPin , LOW);
171 | }
172 | else
173 | digitalWrite (ledPin , LOW);
174 | }
175 | else {
176 | eject();
177 | userIn = false ;
178 | }
179 | }

180
181 | delay(50); // delay in between reads for stability
182 | }

✡✝

✆

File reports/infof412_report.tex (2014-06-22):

\documentclass[10pt,a4paper]{article}

\usepackage[utf8]{inputenc}
\usepackage[T1]{fontenc}
\usepackage[svgnames]{xcolor} % Required to specify font color
%\usepackage{mathpazo} %fancy font used by Anthony
\usepackage{floatrow}
\usepackage{geometry}%réglages mise en page
\geometry{%
a4paper, % note : l'option a4paper tuait la marge supérieure.
body={170mm,250mm}, %
left=25mm,top=25mm,right=25mm, %
headheight=21mm,headsep=7mm,
marginparsep=4mm,
marginparwidth=20mm, %
footnotesep=50mm
}

\usepackage{graphicx}
\usepackage{float}
\usepackage{color}
\usepackage{amssymb}

\usepackage{array}
\usepackage{hyperref}
\usepackage{lscape}

%%% Pour colorier le code source C++/matlab
\usepackage{listings}
\usepackage{xcolor}
\usepackage[colorinlistoftodos]{todonotes}

\definecolor{colKeys}{rgb}{0,0,1}  % couleurs des mots-clés propres au language
\definecolor{colIdentifier}{rgb}{0,0,0}  % couleurs des mots à identifier
\definecolor{colComments}{rgb}{0,0.6,0}  % couleurs des commentaires
\definecolor{colString}{rgb}{0.6,0.1,0.1}

\lstset{language=c++}
\lstset{commentstyle=\color{colComments}\textit, %
basicstyle=\ttfamily\small, %
identifierstyle=\color{colIdentifier}, %
keywordstyle=\color{colKeys}, %
stringstyle=\color{colString}, %
commentstyle=\color{colComments}, %
columns=flexible, %
tabsize=2, %
extendedchars=true, %
showspaces=false, %
showstringspaces=false, %
numbers=left, %
numberstyle=\tiny, %
breaklines=true, %
breakautoindent=true, %
captionpos=b,%
}

\title{INFO-F-412 Formal Verification of Computer Systems\\The GOAT-IE\\ \large{The Gate Opener Action by Ticket -- Improved Edition}}
\author{Quentin Delhaye}

%%%%%%%%%%%%%%%%%%%%%%%%%%%%%%%%%%%%%%%%%%%%%%%%%%%%%%%%%%%%%%%%%%%%%%%%%%%%%%%%%%%

\begin{document} 
\maketitle

%%%%%%%%%%%
\section{Introduction}
%%%%%%%%%%%
This project directly follows the Embedded Systems Design project.
In that project, entitled "\textit{The GOAT}", we modelised a sas with two doors.
When the sas was not occupied, the first door was open for anyone to enter.
Uppon user entering, the first door would close and a timer would begin.
In the given time, the user could present his card to be processed by the sas, or simply leave the sas by the first door.
If the card was accepted, the second door would open for the user to leave.
While doing all those actions, the timer clock would progress, and when reaching its limit, broadcast a signal to the user asking him to leave the sas by the first door, so that he would not stay in there forever.

In the present project, we want to improve the behavior of the sas by adding a queue for him to handle, in order to guarentee a fair sequence of users entering the sas.

%%%%%%%%%%%
\section{Improvement to the models}
%%%%%%%%%%%
The larger part of the models was not modified.
As we want to control the flow of users entering the sas, the new part involves the transition to and from \texttt{User.in\_sas}.

\begin{lstlisting}[caption=Global system declarations., label=lst:globalDecl]
chan infra1, infra2, cardIn, eject;
chan req;//Request channel
clock timeInSas;
const int SAS_TIMER = 10;
const int N_USERS = 2;
int reqID;
int turn;//The ID of the user whose it's turn.
int gateConf = 1;//Binary: g2g1 => 01 = gate 2 closed && gate 1 open, 00 both closed, 10 = gate 2 open && gate 1 closed.
int userCard;
\end{lstlisting}

\subsection{User}
In the user model, we add a new state \texttt{want\_in} that will be a pool in which the user goes if he, as the state name suggests, wants in.
The transition from \texttt{before\_sas} to \texttt{want\_in} triggers a signal \texttt{req} that will be followed in the sas model.

The second and last modification in this system is the new guard on the transition \texttt{want\_in} to \texttt{in\_sas}. Indeed, the user now has to wait for his turn, represented by the variable \texttt{turn} being set to his id.

The figure~\ref{fig:userModel} and listing~\ref{lst:userDecl} present this updated model. It is also to be noted that all users have a copy of the same model.

\begin{figure}[!h]
	\centering
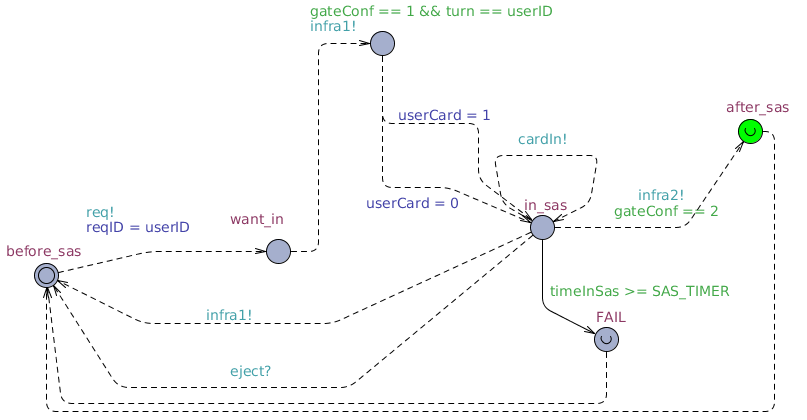
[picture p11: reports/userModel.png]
    
    \caption{New user model with request token.}
    \label{fig:userModel}
\end{figure}

\begin{lstlisting}[caption=Declarations of user model., label=lst:userDecl]
clock x;
const int userID = 1;
\end{lstlisting}

\subsection{Sas}
The first modification is the addition of new self-transitions on \texttt{idle} and \texttt{handling\_user} states for the reception of the signal \texttt{req}.
When receiving the signal, the sas receives the id of the corresponding user and appends it to the queue using the \texttt{addInQueue(int)} function.

When the user enters the sas, the sas model shifts the queue using \texttt{shiftQueue()} so that the next user in line is ready to enter as soon as the sas is available.

The figure~\ref{fig:sasModel} and listing~\ref{lst:sasDecl} present this updated model.

\begin{figure}[!h]
	\centering
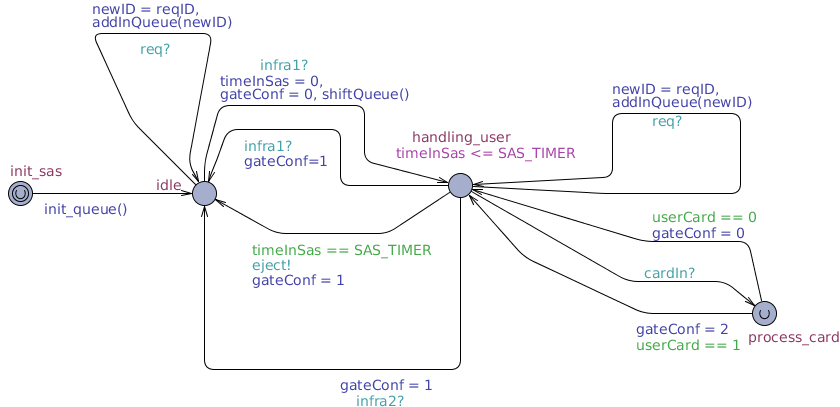
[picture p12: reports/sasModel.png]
    
    \caption{New sas model with queue handling.}
    \label{fig:sasModel}
\end{figure}

%%%%%%%%%%%
\section{Winning conditions}
%%%%%%%%%%%
Some winning condition have already been discussed in the Embedded Systems Design report.
For the new properties of the system, we may add the following expressions using \textsc{CTL}:
\begin{itemize}
	\item $\forall$\verb|[] (User.want_in |$\rightarrow \forall$ \verb|<> User.in_sas)| ~\\
		If the user want to enter the sas, he will enter the sas (liveness).
	\item $\forall$\verb|[] (User.before_sas |$\rightarrow \exists$ \verb|<> User.want_in| ~\\
		If the user is in idle mode, he will be able to request entering inside the sas (non-blocking).
	\item $\forall$\verb|[] not(User.in_sas and User2.in_sas)| ~\\
		Two users can not be in the sas at the same time (safety)\footnote{For the sake of completion, as this property was already presented in the linked project.}.
\end{itemize}

%%%%%%%%%%%
\section{Conclusion}
%%%%%%%%%%%
This project extends the one for Emebdded Systems Design by repairing one of its fault that was one user could monopolize the sas by leaving and entering it directly without giving other user a fair chance to access the said sas.
In a sense, we did enforce some sort of strict sequencing, but only to ensure a certain degree of fairness in the system. 
It is simply the modelisation of a real-life problem: poeple enter a queue to access a ressource that can only be used by one person for a certain amount of time.

If we want to take this project even one step further, we could make the sas two-way, instead of one.
In this improvement, both doors could be closed in idle mode and users could request its access from the first or the second door.
The modelisation would not differ that much, since we can use the same queue to store the requests, and the distribution mechanism of tokens would be sensibly the same.

\newpage
\appendix
%%%%%%%%%%%
\section{Sas declarations}
\begin{lstlisting}[caption=Sas model declarations., label=lst:sasDecl]
clock x;

int queue[N_USERS];
int newID;//Requester's ID

void init_queue()
{	
	int i;
	for(i = 0;i<N_USERS;++i) {
		queue[i] = 0;
	}
}

//Add a new id at the end of the queue
void addInQueue(int id) 
{
	int i;
	int set = 0;
	for(i=0;i<N_USERS && set==0;++i) {
		if(queue[i] == 0) {
			queue[i] = id;
			set = 1;
		}
	}
	turn = queue[0];//Update if necessary
}

//Shift each user one place forward in the queue
void shiftQueue()
{
	int i;
	for(i=0;i<N_USERS-1;++i) {
		queue[i] = queue[i+1];
	}
	queue[N_USERS-1] = 0;//Last place in the queue is available.
	turn = queue[0];//Update if necessary
}
\end{lstlisting}

\end{document}

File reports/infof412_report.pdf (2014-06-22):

## INFO-F-412 Formal Verification of Computer Systems The GOAT-IE

The Gate Opener Action by Ticket – Improved Edition

Quentin Delhaye

June 22, 2014

## 1 Introduction

This project directly follows the Embedded Systems Design project. In that project, entitled "The GOAT", we modelised a sas with two doors. When the sas was not occupied, the first door was open for anyone to enter. Uppon user entering, the first door would close and a timer would begin. In the given time, the user could present his card to be processed by the sas, or simply leave the sas by the first door. If the card was accepted, the second door would open for the user to leave. While doing all those actions, the timer clock would progress, and when reaching its limit, broadcast a signal to the user asking him to leave the sas by the first door, so that he would not stay in there forever.
In the present project, we want to improve the behavior of the sas by adding a queue for him to handle, in order to guarentee a fair sequence of users entering the sas.

## 2 Improvement to the models

The larger part of the models was not modified. As we want to control the flow of users entering the sas, the new part involves the transition to and from User.in_sas.

1 | chan infra1, infra2, cardIn, eject;
2 | chan req;//Request channel
3 | clock timeInSas;
4 | const int SAS_TIMER = 10;
5 | const int N_USERS = 2;
6 | int reqID;
7 | int turn;//The ID of the user whose it’s turn.
8 | int gateConf = 1;//Binary: g2g1 => 01 = gate 2 closed && gate 1 open, 00 both closed, 10 = gate
| 2 open && gate 1 closed.
9 | int userCard;
Listing 1: Global system declarations.

### 2.1 User

In the user model, we add a new state want_in that will be a pool in which the user goes if he, as the state name suggests, wants in. The transition from before_sas to want_in triggers a signal req that will be followed in the sas model.
The second and last modification in this system is the new guard on the transition want_in to in_sas. Indeed, the user now has to wait for his turn, represented by the variable turn being set to his id.
The figure 1 and listing 2 present this updated model. It is also to be noted that all users have a copy of the same model.
1 | clock x;
2 | const int userID = 1;
Listing 2: Declarations of user model.

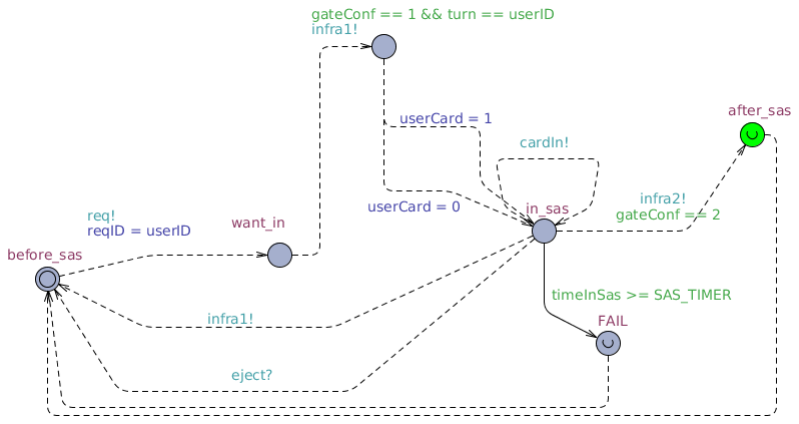
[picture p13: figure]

Figure 1: New user model with request token.

### 2.2 Sas

The first modification is the addition of new self-transitions on idle and handling_user states for the reception of the signal req. When receiving the signal, the sas receives the id of the corresponding user and appends it to the queue using the addInQueue(int) function.
When the user enters the sas, the sas model shifts the queue using shiftQueue() so that the next user in line is ready to enter as soon as the sas is available.
The figure 2 and listing 3 present this updated model.


Figure 2: New sas model with queue handling.

## 3 Winning conditions

Some winning condition have already been discussed in the Embedded Systems Design report. For the new properties of the system, we may add the following expressions using CTL:

- ∀[] (User.want_in → ∀ <> User.in_sas)
If the user want to enter the sas, he will enter the sas (liveness).
- ∀[] (User.before_sas → ∃ <> User.want_in
If the user is in idle mode, he will be able to request entering inside the sas (non-blocking).
- ∀[] not(User.in_sas and User2.in_sas)
Two users can not be in the sas at the same time (safety)¹

## 4 Conclusion

This project extends the one for Emebdded Systems Design by repairing one of its fault that was one user could monopolize the sas by leaving and entering it directly without giving other user a fair chance to access the said sas. In a sense, we did enforce some sort of strict sequencing, but only to ensure a certain degree of fairness in the system. It is simply the modelisation of a real-life problem: poeple enter a queue to access a ressource that can only be used by one person for a certain amount of time.
If we want to take this project even one step further, we could make the sas two-way, instead of one. In this improvement, both doors could be closed in idle mode and users could request its access from the first or the second door. The modelisation would not differ that much, since we can use the same queue to store the requests, and the distribution mechanism of tokens would be sensibly the same.

1For the sake of completion, as this property was already presented in the linked project.

## A Sas declarations

clock x;

int queue[N_USERS];
int newID;//Requester’s ID

void init_queue()

{
int i;
for(i = 0;i<N_USERS;++i) { queue[i] = 0;

}

}

//Add a new id at the end of the queue void addInQueue(int id)

{
int i;
int set = 0;
for(i=0;i<N_USERS && set==0;++i) { if(queue[i] == 0) {
queue[i] = id;
set = 1;

}

}
turn = queue[0];//Update if necessary

}

//Shift each user one place forward in the queue void shiftQueue()

{
int i;
for(i=0;i<N_USERS-1;++i) {
queue[i] = queue[i+1];

}
queue[N_USERS-1] = 0;//Last place in the queue is available. turn = queue[0];//Update if necessary

}
Listing 3: Sas model declarations.

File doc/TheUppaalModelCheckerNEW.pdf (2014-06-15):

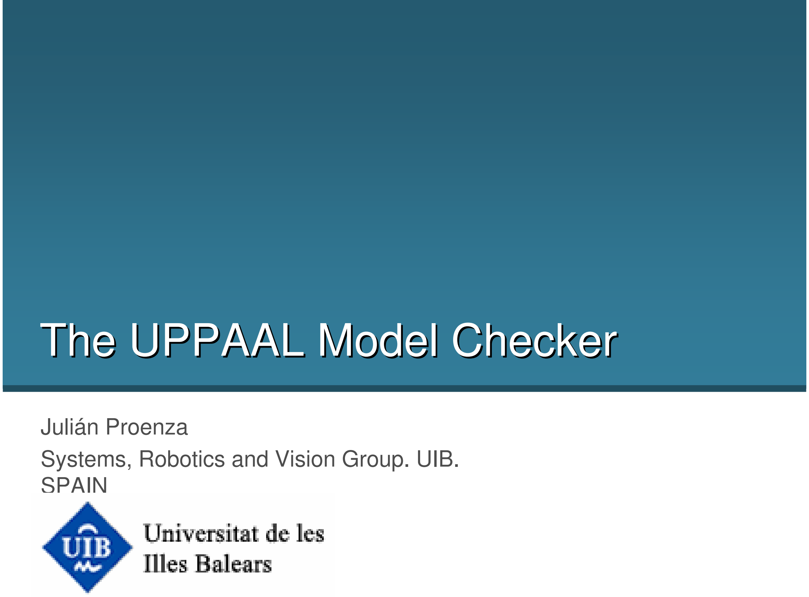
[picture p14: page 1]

# The UPPAAL Model Checker

Julián Proenza
Systems, Robotics and Vision Group. UIB. SPAIN

2

Julián Proenza. UIB. Oct 2008

# The aim of this presentation

### - Introduce the basic concepts of model checking from a practical perspective

### - Describe the basic features of the UPPAAL model

### checker

### - Use examples to illustrate the practical use of

### UPPAAL for the formal verification of systems

3

# Presentation Outline

### 1. The role of Model Checking in design validation

### 2. The UPPAAL Tool

### 1. Introduction 2. Modeling 3. Verification 4. A first example 5. Installation instructions

### 3. References

4

# Presentation Outline

### 1. The role of Model Checking in design validation

### 2. The UPPAAL Tool

### 1. Introduction 2. Modeling 3. Verification 4. A first example 5. Installation instructions

### 3. References

5

# The need for Design Validation

### - Hardware and software are widely used in applications

### where failure is unacceptable

### - Design Validation is necessary: ensuring design correctness at the earliest stage possible

- Traditional Techniques (rarely get exhaustive validation): – Simulation (on an abstraction or a model of the system) – Testing (on the actual product)
- Formal Methods (aimed at exhaustive validation) – Deductive Verification (costly, slow and only partially automatic) – Model Checking (for finite-state concurrent systems automatic)

6

# The Model Checking Technique

### - Use of Formal Methods has been considered for a long time a very desirable task for ensuring the correct design of a system

### - The complexity of these methods made them only

accessible to specialists (mathematicians). – Thus they were actually only used for very critical systems

### - Model Checking is the first technique that is truly

accessible for “normal” engineers – Enabling the use of formal verification in a wider spectrum of

applications (including VHDL systems) – Applicable to (finite-state concurrent systems) sequential

circuits, communication protocols, software…

7

# The 3 Steps of Model Checking

### 1. Build a model for the system, typically as a set of automata 2. Formalize the properties to be verified using expressions in a logic 3. Use the model checker (a tool) to generate the space of all possible

states and to exhaustively check whether the properties hold in each and everyone of the possible DYNAMIC BEHAVIOURS of the model

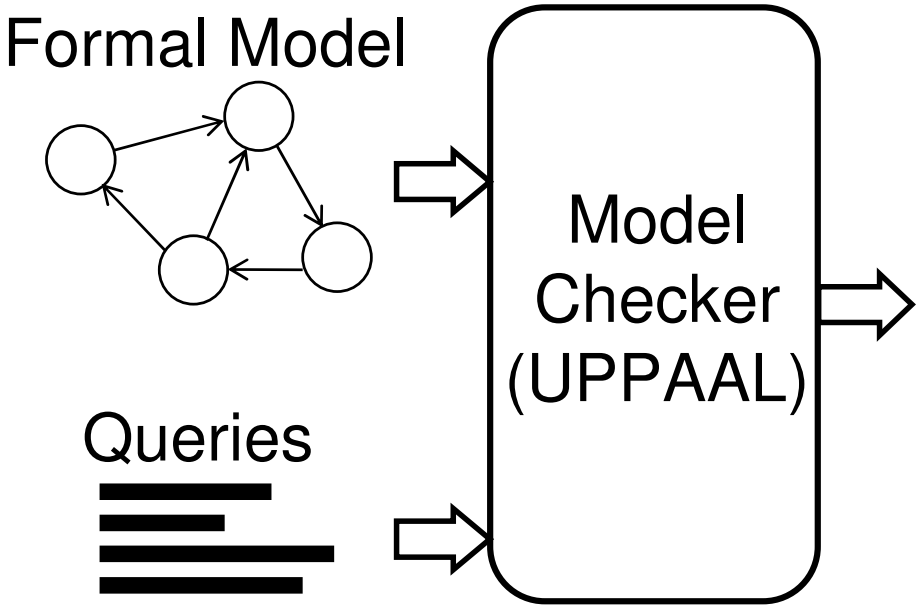
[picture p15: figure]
Model Checker (UPPAAL); Formal Model; Queries

### Yes

or

### No (counterexample)

### For each query

8

# Presentation Outline

### 1. The role of Model Checking in design validation

### 2. The UPPAAL Tool

### 1. Introduction 2. Modeling 3. Verification 4. A first example

9

# Introducing UPPAAL (v4.0.6)…

### - UPPAAL is a tool box for validation (via graphical simulation) and verification (via automatic model-

checking) of real-time systems.

- It consists of two main parts: – a Graphical User Interface (GUI) (executed on the users work

station) and – a model-checker engine (by default executed on the same

computer as the user interface, but can also run on a more powerful server)

### - It has been jointly developed by Uppsala University in Sweden and Aalborg University in Denmark

10

# An overview of the tool

Menu
Icons
Tabs

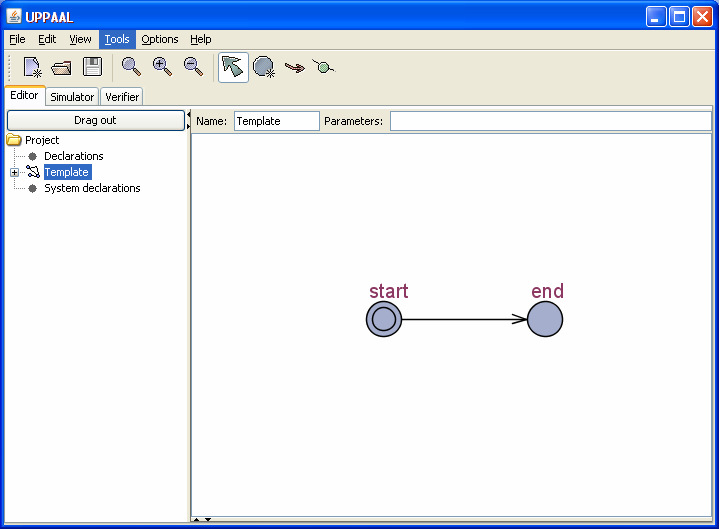
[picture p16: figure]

11

Julián Proenza. UIB. Oct 2008 An overview of the tool

# The Editor Window

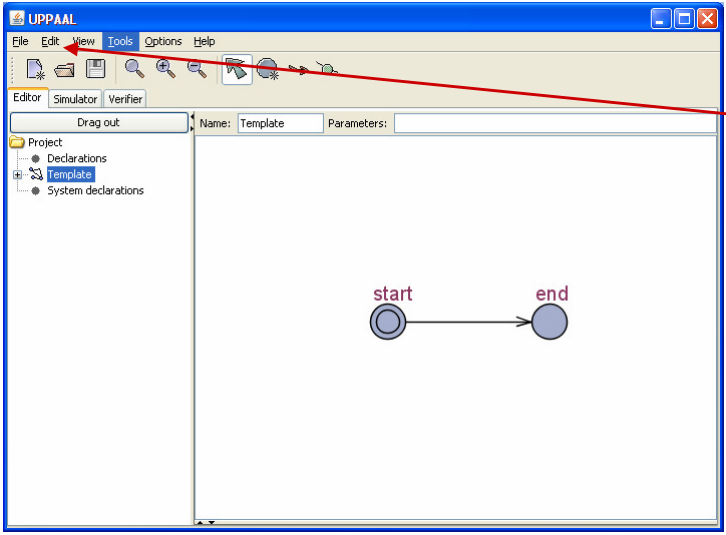
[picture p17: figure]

12

Julián Proenza. UIB. Oct 2008 An overview of the tool

# The Editor Window

With
“undo”!

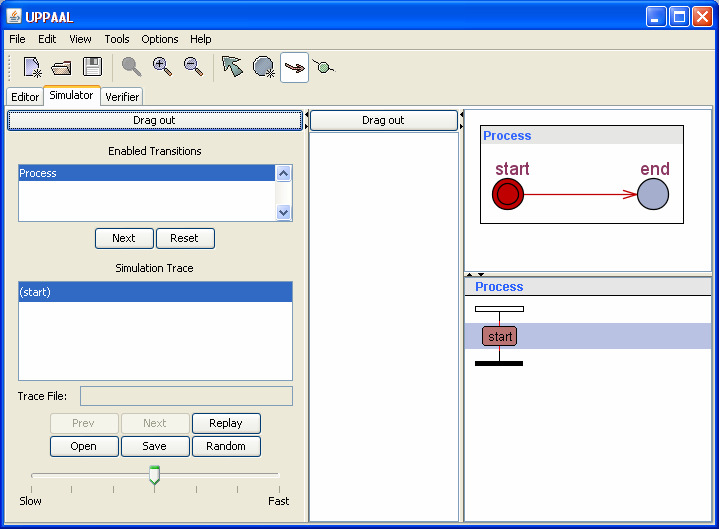
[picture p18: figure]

13

Julián Proenza. UIB. Oct 2008 An overview of the tool

# The Simulator Window (1)

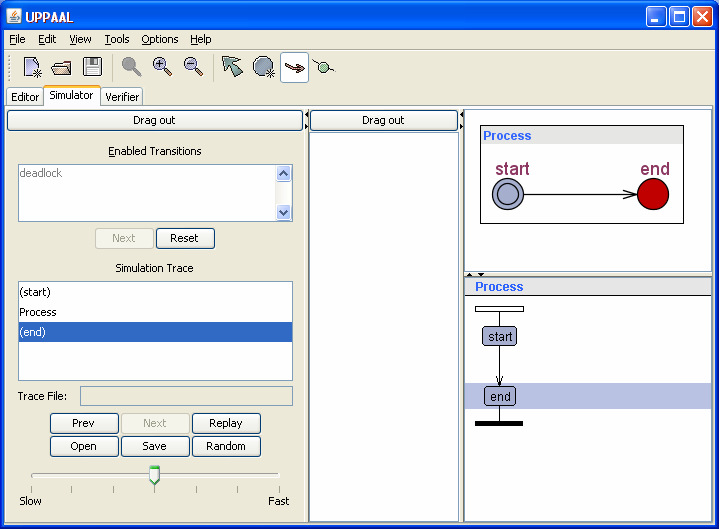
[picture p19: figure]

14

Julián Proenza. UIB. Oct 2008 An overview of the tool

# The Simulator Window (2)

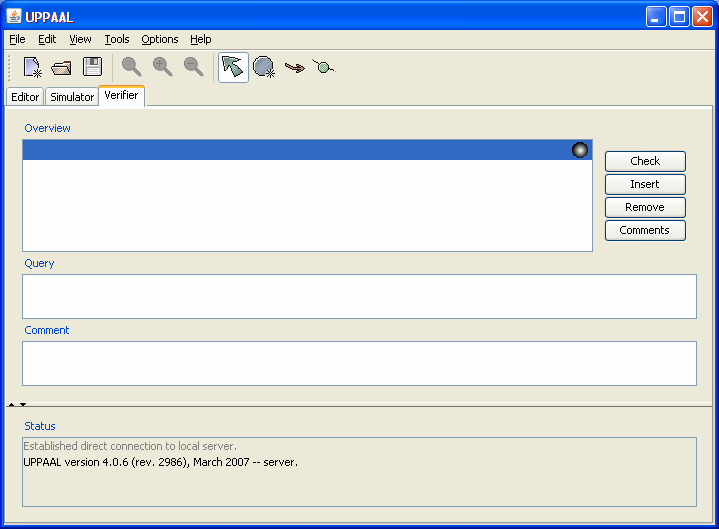
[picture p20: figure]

15

Julián Proenza. UIB. Oct 2008 An overview of the tool

# The Verifier Window (1)

16

Julián Proenza. UIB. Oct 2008 An overview of the tool

# The Verifier Window (2)

### 2. Edit

### 1. Click

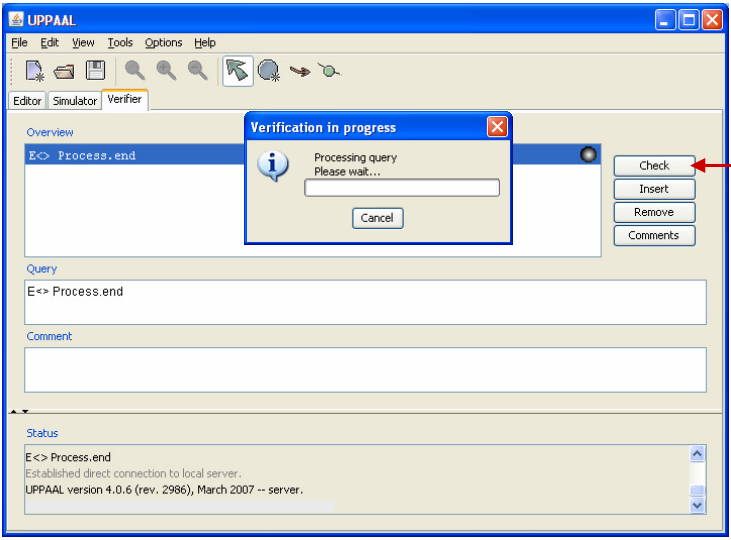
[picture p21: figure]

17

Julián Proenza. UIB. Oct 2008 An overview of the tool

# The Verifier Window (3)

Click

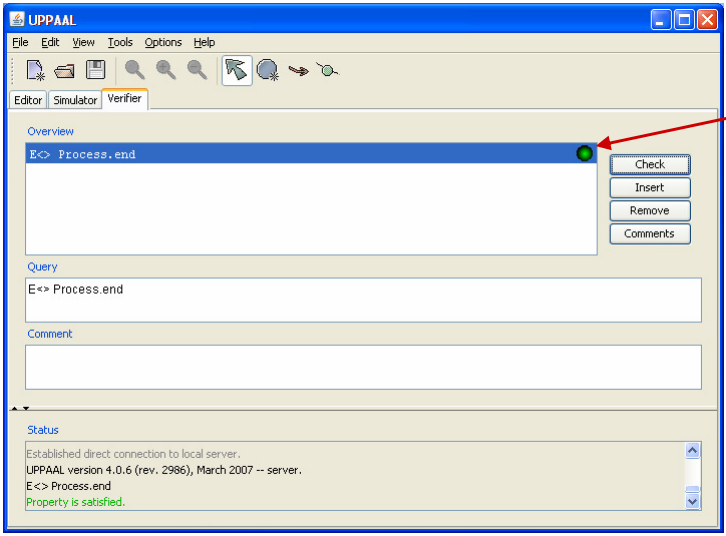
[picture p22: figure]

18

Julián Proenza. UIB. Oct 2008 An overview of the tool

# The Verifier Window (4)

Green
light

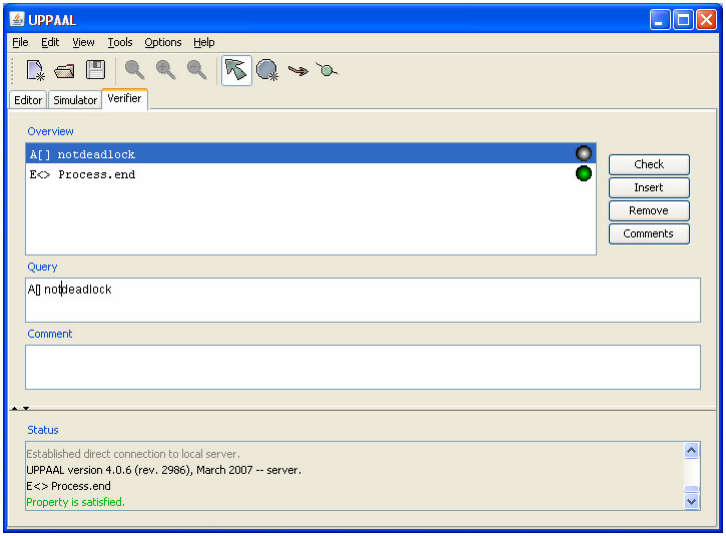
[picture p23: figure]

19

Julián Proenza. UIB. Oct 2008 An overview of the tool

# The Verifier Window (5)

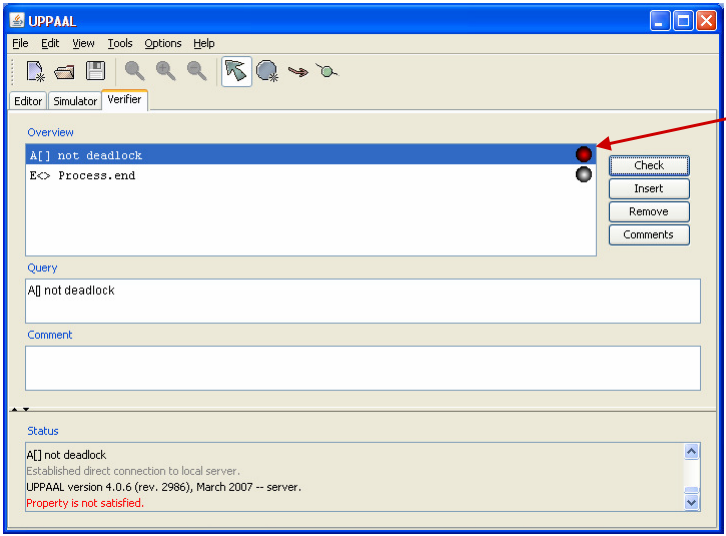
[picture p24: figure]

20

Julián Proenza. UIB. Oct 2008 An overview of the tool

# The Verifier Window (6)

Red
light

# The Verifier Window (7)

21

Julián Proenza. UIB. Oct 2008 An overview of the tool

Options
Diagnostic Trace
Some

# The Stored Trace (counterexample)

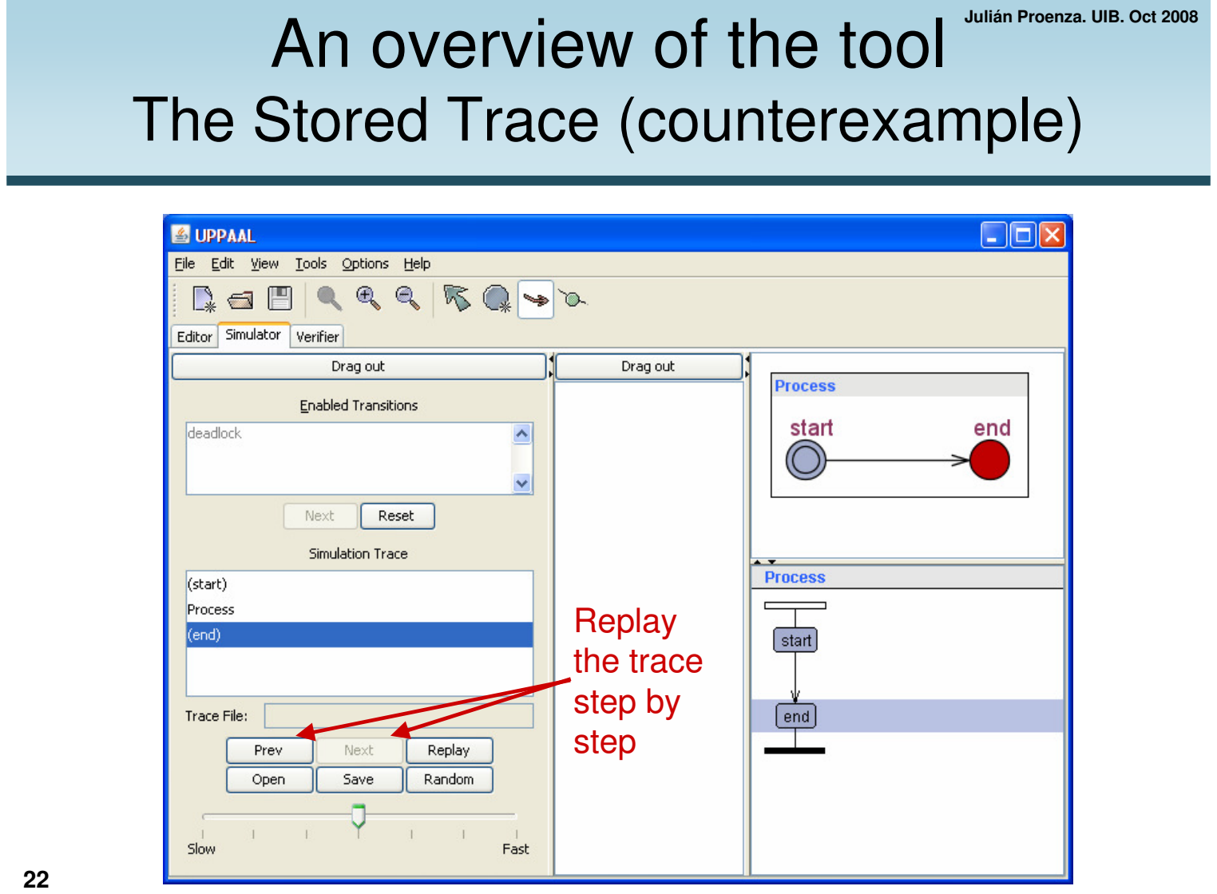
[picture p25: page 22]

22

Julián Proenza. UIB. Oct 2008 An overview of the tool

Replay
the trace
step by
step

23

# Presentation Outline

### 1. The role of Model Checking in design validation

### 2. The UPPAAL Tool

### 1. Introduction 2. Modeling 3. Verification 4. A first example 5. Installation instructions

### 3. References

24

# Modeling with UPPAAL

### - In UPPAAL, systems are modeled using timed-

automata, which are finite state machines with clocks. – Clocks are variables which can evaluate to a real number and

which can be defined in each automaton in order to measure the time progress. – All clocks evolve at the same pace in order to represent the

global progress of time. – The actual value of a clock can be either tested or reset (not

assigned).

### - Given that UPPAAL is specially designed for the

### verification of real-time systems, clocks are a

fundamental modeling and verification feature.

25

# Structure of an UPPAAL Model

### - An UPPAAL model is built as a set of concurrent

processes.

### - Each process is graphically designed as a timed-

automaton.

### - Since instantiations of the same automaton are frequently needed templates are used - A timed-automaton is represented as a graph which has locations as nodes and edges as arcs between

locations.
start | end

26

# Structure of an UPPAAL Model

### - An UPPAAL model is built as a set of concurrent

processes.

### - Each process is graphically designed as a timed-

automaton.

### - Since instantiations of the same automaton are frequently needed templates are used - A timed-automaton is represented as a graph which has locations as nodes and edges as arcs between

locations.

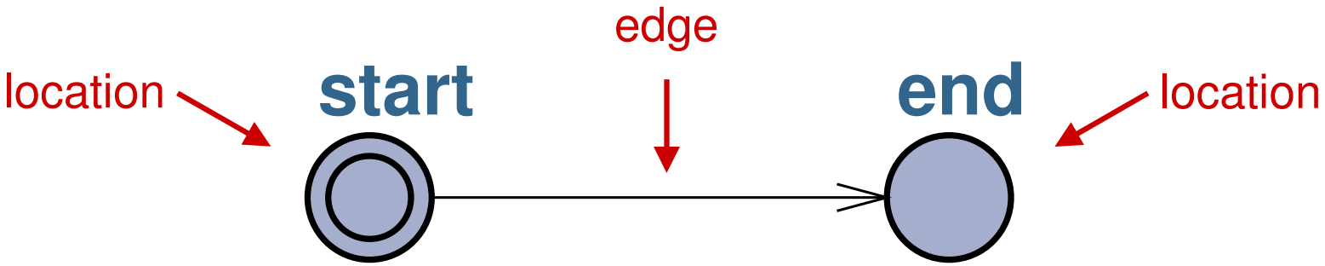
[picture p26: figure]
location; edge; start; end

27

# Labels in Edges

- Edges are annotated with guards, updates,

### synchronisations and selections

28

Julián Proenza. UIB. Oct 2008 Labels in Edges

# Guards

- Edges are annotated with guards, updates,

### synchronisations and selections

### - A guard is an expression which uses the variables and clocks of the model in order to indicate when the

transition is enabled, i.e. may be fired. – Note that several edges may be enabled at an specific time but

only one of them will be fired leading to different potential interleavings
start | end a==1

29

Julián Proenza. UIB. Oct 2008 Labels in Edges

# Updates

### - An update is an expression that is evaluated as soon as the corresponding edge is fired. This evaluation

changes the state of the system.

start | end a==1

b=0

30

Julián Proenza. UIB. Oct 2008 Labels in Edges

# Synchronisations

### - The synchronization is the basic mechanism used to coordinate the action of two or more processes. Models for instance the effect of messages

### - It causes two (or more) processes to take a transition at the same time. A channel (c) is declared, then one process will have an edged annotated with c! and the other(s) process(es) another edge annotated with c?

- Three different kinds of synchronizations: – Regular channel (leading to Binary Synchronization) – Urgent channel – Broadcast channel

31

Julián Proenza. UIB. Oct 2008 Labels in Edges

# Synchronisations: Regular Channel

- A regular channel is declared as, e.g., chan c. – When a process is in a location from which there is a transition

labelled with c! the only way for the transition to be enabled is that another process is in a location from which there is a transition labelled with c? and vice versa. – If at a specific instant there are several possible ways to have

a pair c! and c?, one of them is non-deterministically chosen during model checking. – The update expression on an edge synchronizing on c! is

executed before the update expression on an edge synchronizing on c?

start | end a==1 c!

b=0

start | end a==1 c?

b=0

32

Julián Proenza. UIB. Oct 2008 Labels in Edges

# Synchronisations: Urgent Channel

- An urgent channel is declared as urgent chan c. – Urgent channels are similar to regular channels, except that it

is not possible to delay in the source state if it is possible to trigger a synchronisation over an urgent channel. – This means no time can pass but they can interleave with

other transitions that require no time to pass. – Graphically they look like regular channels – Notice that clock guards are not allowed on edges

synchronising over urgent channels

start | end a==1 c!

b=0

start | end a==1 c?

b=0

33

Julián Proenza. UIB. Oct 2008 Labels in Edges

# Synchronisations: Broadcast Channel

- For a broadcast channel: broadcast chan c. – When one process is in a location from which there is a

transition labelled with c! and one or more processes are in locations from which there is a transition labelled with c? all these transitions are enabled. – However, if there are no processes in locations from which

there is a transition labelled with c?, the transition labelled with c! is enabled anyway. – Notice that clock guards are not allowed on edges receiving

on a broadcast channel. – The update on the emitting edge is executed first. The update

on the receiving edges are executed left-to-right in the order the processes are given in the system definition.

start | end a==1 c!

b=0

start | end a==1 c?

b=0

start | end a==1 c?

b=0

34

# Locations

### - Locations can have an optional name (as seen in

previous slides) – Names are useful to refer to the location during model checking

and when documenting the model

### - Locations can be of three different types (that can

be assigned by double-clicking on the location): – Initial – Urgent – Committed – Normal (all the rest)

35

Julián Proenza. UIB. Oct 2008 Location Types

# Initial

### - Each template must be properly initialized, meaning it must start in a specific location. Therefore, each template must have exactly one location marked as

initial.

### - Initial locations are identified with a double circle

start | end

Initial location

36

Julián Proenza. UIB. Oct 2008 Location Types

# Urgent

### - Urgent locations freeze time; i.e. time is not allowed to

pass when a process is in an urgent location. – The location must be left before time could pass – Other transitions may happen before, as long as they do not

require time to pass

### - Urgent locations are identified with a “U”

urgent location

### - Clock x will not increase as long as in loc1

start | loc1 | end x=0

37

Julián Proenza. UIB. Oct 2008 Location Types

# Committed

### - Committed locations also freeze time; i.e. time is not

allowed to pass when a process is in one of them. – When a model has one or more active committed locations, no

transitions other than those leaving said locations can be enabled. – Notice that if several processes are in a committed location at the

same time, then they will interleave. – Committed locations are useful for creating atomic sequences

### - Committed locations are identified with a “C”

### - Clock x will not increase as long as in loc1

start | loc1 | end x=0

38

# Invariants

- Both initial and normal locations can have invariants.

### - Invariants are conditions that must be fulfilled while the

automaton is in that location.
- They can be related to variables and clocks.
loc1 | end

a!=b

### start

loc1 | end

x<=T

start x=0 | x==T

39

# Invariants on clocks and time (1)

### - To better understand the role invariants on clocks

### play let us consider the following examples (proposed

at the UPPAAL tutorial) – The goal is to achieve a similar behaviour (stay in a location

until a condition on a clock holds and then leave the location) – First attempt without an invariant – Note that the “observer” allows the observation of the clock

value at different instants (clearer when completing the tutorial)

### loop x>=2

### reset!

idle | taken

x=0

### reset?

40

# Invariants on clocks and time (1)

### - To better understand the role invariants on clocks

### play let us consider the following examples (proposed

at the UPPAAL tutorial) – The goal is to achieve a similar behaviour (stay in a location

until a condition on a clock holds and then leave the location) – First attempt without an invariant – Note that the “observer” allows the observation of the clock

value at different instants (clearer when completing the tutorial)

loop | x>=2

time; Clock x

reset! | 2

41

# Invariants on clocks and time (2)

### - To better understand the role invariants on clocks

### play let us consider the following examples (proposed

at the UPPAAL tutorial) – The goal is to achieve a similar behaviour (stay in a location

until a condition on a clock holds and then leave the location) – Second attempt without an invariant

idle | taken

x=0

### reset? loop x==2

### reset!

42

# Invariants on clocks and time (2)

### - To better understand the role invariants on clocks

### play let us consider the following examples (proposed

at the UPPAAL tutorial) – The goal is to achieve a similar behaviour (stay in a location

until a condition on a clock holds and then leave the location) – Second attempt without an invariant

loop | x==2

time; Clock x

reset! | 2

43

# Invariants on clocks and time (3)

### - To better understand the role invariants on clocks

### play let us consider the following examples (proposed

at the UPPAAL tutorial) – The goal is to achieve a similar behaviour (stay in a location

until a condition on a clock holds and then leave the location) – Third attempt without an invariant (that will obviously have

the same problem!)

idle | taken

x=0

reset? loop x>=2,
x<=3

### reset!

time; Clock x

44

# Invariants on clocks and time (3)

### - To better understand the role invariants on clocks

### play let us consider the following examples (proposed

at the UPPAAL tutorial) – The goal is to achieve a similar behaviour (stay in a location

until a condition on a clock holds and then leave the location) – Third attempt without an invariant (that will obviously have

the same problem!)

loop | x>=2, x<=3
| reset!

45

# Invariants on clocks and time (4)

### - To better understand the role invariants on clocks

### play let us consider the following examples (proposed

at the UPPAAL tutorial) – The goal is to achieve a similar behaviour (stay in a location

until a condition on a clock holds and then leave the location) – Finally with an invariant

idle | taken

x=0

### reset? loop

x<=2

x==2

### reset!

46

# Invariants on clocks and time (4)

### - To better understand the role invariants on clocks

### play let us consider the following examples (proposed

at the UPPAAL tutorial) – The goal is to achieve a similar behaviour (stay in a location

until a condition on a clock holds and then leave the location) – Finally with an invariant

### loop

x<=2

x==2

time; Clock x

### reset! 2

47

# Invariants on clocks and time (5)

### - To better understand the role invariants on clocks

### play let us consider the following examples (proposed

at the UPPAAL tutorial) – The goal is to achieve a similar behaviour (stay in a location

until a condition on a clock holds and then leave the location) – A different behaviour with an invariant

idle | taken

x=0

### reset? loop

x<=3

x>=2

### reset!

48

# Invariants on clocks and time (5)

### - To better understand the role invariants on clocks

### play let us consider the following examples (proposed

at the UPPAAL tutorial) – The goal is to achieve a similar behaviour (stay in a location

until a condition on a clock holds and then leave the location) – A different behaviour with an invariant

### loop

x<=3

x>=2

time; Clock x

### reset! 2

49

# Invariants on clocks and time (6)

### - A final note: Semantically, urgent locations are

equivalent to: – adding an extra clock, x, that is reset on every incoming edge,

and – adding an invariant x <= 0 to the location.

loc1 | end

x<=0

### start x=0

start | loc1 | end

50

# Some modeling tricks

### - They are often necessary to actually reproduce the

behaviour of our system.

### - It is possible to encode “urgent transitions” with a guard on a variable, i.e. busy wait on a variable, by using urgent

channels. – Use a dummy automaton with one state looping with one transition

read!. The urgent transition will be x>0 read? for example.

### - There is no value passing though the channels but this

is easily encoded by a shared variable: – Define globally a variable x, and use it to write and read it. Notice

that it is not clean to do read! x:=3; and read? y:=x; but it is better to use a commit state: read? commit state and y:=x;.

51

# A recommendation on modeling

### - The state space grows very quickly with the model

complexity (state space explosion). It is necessary to: – Find the suitable level of abstraction for the model – Model only the features related to the properties to be verified – Also omit the features that are “obviously” correct

- More specifically: – The number of clocks has an important impact on the complexity – The use of committed locations can reduce significantly the state

space, but it can possibly take away relevant states. – The number of variables is also relevant and even more their

range. In particular, avoid unbounded loops on integers since the values will then span over the full range.

### - This is rather an “art” (so model checking is not so “perfect” as it initially looks but it helps to think)

52

# Presentation Outline

### 1. The role of Model Checking in design validation

### 2. The UPPAAL Tool

### 1. Introduction 2. Modeling 3. Verification 4. A first example 5. Installation instructions

### 3. References

53

# Verifying with UPPAAL

### - After using the simulator to ensure that the model

### behaves as the system we wanted to model (and sometimes also to detect some errors in the original

### design), the next phase is to check that the model verifies the properties

### - Then we need to know/decide what those properties

are… and formalize them! – Ex. from def. of consensus service: Consistency: All correct

servers agree on the same value and all decisions are final.

### - After that, we have to translate those properties into

### the UPPAAL query language (not one-to-one)

54

# The UPPAAL Query Language

### - The types of properties that can be directly checked

using the UPPAAL queries are quite simple.

### - UPPAAL designers have taken this approach, instead of allowing complex queries, in order to improve the

efficiency of the tool.

### - For this reason the verification of complex properties may need the checking of many different queries and even the addition to the model of specifically designed “testing automata”

55

# Types of Queries in UPPAAL

### - The specific types of properties that can be expressed

in the UPPAAL query language can be classified as: – Reachability properties. A specific condition holds

in some state of the model’s potential behaviours – Safety properties. A specific condition holds in all

### the states of an execution path – Liveness properties. A specific condition is

guaranteed to hold eventually (= at some moment) – Deadlock properties. A deadlock is possible or not

### in the model

56

# UPPAAL Reachability properties

### A specific condition holds in some state of the model’s potential behaviours

### - They are always expressed in the form:

### E<> p “Exists eventually p” meaning there is an execution path in which p eventually (in some state of the path) holds

57

# UPPAAL Reachability properties

### A specific condition holds in some state of the model’s potential behaviours

### - They are always expressed in the form:


### E<> p “Exists eventually p” meaning there is an execution path in which p eventually (in some state of the path) holds

Some
path

Some
state

# UPPAAL Safety properties

“Exists globally p”; “Always globally p”

A specific condition holds in all the states of an
execution path. Two possibilities:
meaning there is an execution
path in which p holds for all
the states of the path

For each (all) execution path
p holds for all the states of
the path

# UPPAAL Liveness properties

“q always leads to p”

A specific condition is guaranteed to hold eventually
(= at some moment). Two possibilities:
A<> p “Always eventually p”
For each (all) execution path
p holds for at least one state
of the path

Any path that “starts” with a
state in which q holds reaches
later a state in which p holds

60

# UPPAAL Deadlock properties

A deadlock is possible or not in the model.

### - A state is in a deadlock if it is impossible that the model evolves to a successor state neither by waiting some time nor by a transition between locations, i.e. there are no enabled transitions

- Two typical examples: – E<> deadlock = “Exists deadlock” – A[] not deadlock = “There is no deadlock”

### - Note that the word “deadlock” can be used inside any expression formalizing a specific property

61

# Some remarks on verification

### - When using model checking for verifying a system, it is usually studied whether there is any deadlock in the

model or not – A deadlock can be evidence of a design error but not necessarily – It could be enough to verify that deadlock only happens when

expected. E.g. :
A[] deadlock imply (cont==max and autom.end)
- Even using abstraction the state space may explode.
There are verification options that may help. – If some options are enabled, the output of the verifier might be

that property is "maybe satisfied".The verifier cannot determine the truth value of the property due to the approximations used.

62

# Presentation Outline

### 1. The role of Model Checking in design validation

### 2. The UPPAAL Tool

### 1. Introduction 2. Modeling 3. Verification 4. A first example 5. Installation instructions

### 3. References

63

# A simple example from the tutorial (1)

- A mutex algorithm. Specification.
Process 1 | Process 2
req1=1; | req2=1;
turn=2; | turn=1;
while(turn!=1 && req2!=0); | while(turn!=2 && req1!=0);
//critical section | //critical section
job1(); | job2();
req1=0; | req2=0;

64

# A simple example from the tutorial (2)

- A mutex algorithm. Modeling with UPPAAL.

Process 1; idle:; req1=1;; want:; turn=2;; wait:; while(turn!=1 && req2!=0);; //critical section; job1();; wait; idle; want; req2==0; turn==me; req1=0; turn=(me==1? 2:1); req1=1

//and return to idle
req1=0;

A[] not(P1.CS and P2.CS)
E<> P1.CS

65

# Presentation Outline

### 1. The role of Model Checking in design validation

### 2. The UPPAAL Tool

### 1. Introduction 2. Modeling 3. Verification 4. A first example 5. Installation instructions

### 3. References

66

# Installation Instructions

- Make sure you have the Java version 5 installed. – E.g.: www.java.com/es/download/manual.jsp

### - Go to the UPPAAL page: www.uppaal.com

### - Click on the download tag and then on the link Uppaal 4.0 (current official release)

### - Fill the license agreement form. Click on “Register & Download”

### - Unzip files

### - To run UPPAAL double-click the file uppaal.jar

67

# Presentation Outline

### 1. The role of Model Checking in design validation

### 2. The UPPAAL Tool

### 1. Introduction 2. Modeling 3. Verification 4. A first example 5. Installation instructions

### 3. References

68

# References

### Some used to create this presentation and some useful for further reading

- UPPAAL (all available at www.uppaal.com) – Uppaal2k: Small Tutorial. 16 October 2002 – G. Behrmann, A. David, and K. G. Larsen. A Tutorial on Uppaal – UPPAAL Online Help
- Model Checking – C. Baier and J.-P. Katoen. Principles of Model Checking. MIT

Press. 2008. – E.M. Clarke, O. Grumberg and D.A. Peled. Model Checking.

The MIT Press. 2000.

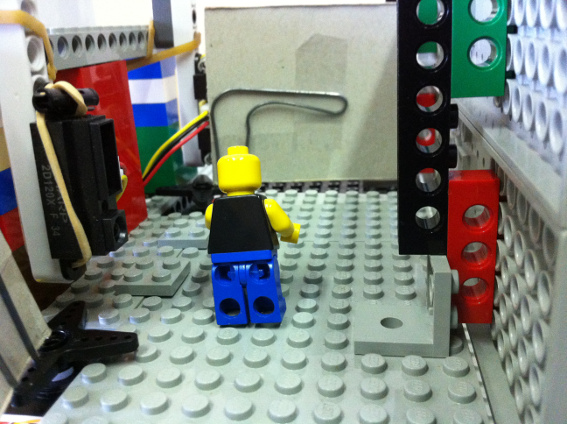
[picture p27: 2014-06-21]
reports/embedded-sytem-design/photo.JPG

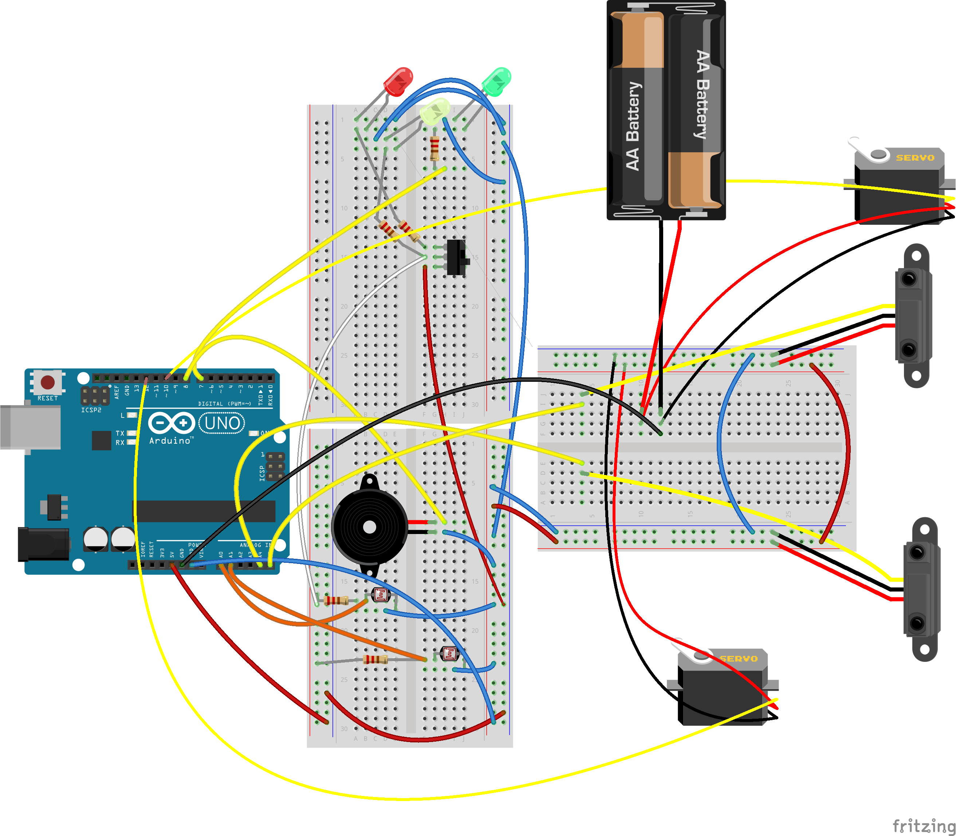
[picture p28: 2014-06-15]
goat2_bb.png

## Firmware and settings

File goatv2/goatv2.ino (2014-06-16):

// Sweep
// by BARRAGAN <http://barraganstudio.com> 
// This example code is in the public domain.

//unsigned long time = millis(); return elapsed milliseconds since startup.


#include <Servo.h> 

Servo myservo;  // create servo object to control a servo 
// a maximum of eight servo objects can be created
Servo servo2; 

int pos;    // variable to store the servo position 
int pos2;

const int ledPin =  7;      // the number of the LED pin
const int buz = 8;
int buzCount = 0;

int gateConf;
unsigned long startTime;
const int SAS_TIMER = 5000;
boolean userIn;
boolean userLeaving;//User is leaving, in infra1

#define but1 A4
#define but2 A5
#define infra1 (analogRead(A4) > 550)
int infra1Count;
#define infra2 (analogRead(A5) > 500)
int infra2Count;
#define cardIn (analogRead(A0) > 0 && analogRead(A1) > 0)

void setup() 
{ 
  pos = 0;//Opened
  pos2 = 90;//Closed
  myservo.attach(9);  // attaches the servo on pin 9 to the servo object 
  servo2.attach(11);
  Serial.begin(9600);
  myservo.write(pos);
  delay(150);
  servo2.write(pos2);
  delay(150);
  
  // set the digital pin as output:
  pinMode(ledPin, OUTPUT);
  pinMode(buz, OUTPUT);
  
  gateConf = 1;
  userIn = false;
  userLeaving = false;
  infra1Count = 0;
  infra2Count = 0;
} 

void changeGateConf(int conf)
{
  gateConf = conf;
  switch (conf) {
    case 0:
      //from 1
      //Close gate 1
      for(pos; pos < 90; pos += 1)  // goes from 0 degrees to 180 degrees 
      {                                  // in steps of 1 degree 
        //Serial.print("Closing gate1: ");
        //Serial.println(pos);
        myservo.write(pos);              // tell servo to go to position in variable 'pos' 
        delay(15);                       // waits 15ms for the servo to reach the position 
      }
      //We could simply write myservo.write(90), but the rotation would be too quick.
      //gate 2 already closed
      break;
     case 1:
       Serial.println("Close gate2 and open gate1");
    
      //Open gate 1 : 0->90
      //Close gate 2 : 180->90
      for(pos2; pos2 > 90; pos2 -= 1)  // goes from 0 degrees to 180 degrees 
      {      // in steps of 1 degree 
        //Serial.print("Closing gate2: ");
        //Serial.println(pos2);
        servo2.write(pos2);              // tell servo to go to position in variable 'pos' 
        delay(15);                       // waits 15ms for the servo to reach the position 
      }
      for(pos; pos > 0; pos -= 1)  // goes from 0 degrees to 180 degrees 
      {                                  // in steps of 1 degree
        //Serial.print("Opening gate1: ");
        //Serial.println(pos);
        myservo.write(pos);              // tell servo to go to position in variable 'pos' 
        delay(15);                       // waits 15ms for the servo to reach the position 
      }
      break;
     case 2:
       //gateConf = 2
      //Close gate 1: 90->0
      //Open gate 2: 0->90
      Serial.println("Close gate1 and open gate2");
      
      
      for(pos; pos < 90; pos += 1)  // goes from 0 degrees to 180 degrees 
      {                                  // in steps of 1 degree 
        //Serial.print("Closing gate1: ");
        //Serial.println(pos);
        myservo.write(pos);              // tell servo to go to position in variable 'pos' 
        delay(15);                       // waits 15ms for the servo to reach the position 
      }
      for(pos2; pos2 < 180; pos2  += 1)  // goes from 0 degrees to 180 degrees 
      {                                  // in steps of 1 degree 
        //Serial.print("Opening gate2: ");
        //Serial.println(pos2);
        servo2.write(pos2);              // tell servo to go to position in variable 'pos' 
        delay(15);                       // waits 15ms for the servo to reach the position 
      }
      break;
      
     default:
       Serial.println("BIG PROBLEEM.");
       break;
  }  
}

boolean processCard()
{
  int sensorValue = analogRead(A0);
  int sensorValue2 = analogRead(A1);
  if(sensorValue>200 && sensorValue<400 && sensorValue2>200 && sensorValue2<400)
    return true;
  else
    return false;
}

void alarm(boolean on)
{
  if(on) {
    int i;
    if(buzCount < 9) {
      for(i=0; i<10; i++)
      {
        digitalWrite(buz, HIGH);
        delay(3);//Shorter delay = higher pitch
        digitalWrite(buz, LOW);
        delay(3);
      }
      buzCount ++;
    }
    else {
      for(i=0; i<10; i++)
      {
        digitalWrite(buz, HIGH);
        delay(18);
        digitalWrite(buz, LOW);
        delay(18);
      }
      buzCount = 0;
    }
  }
}

void eject()
{
  digitalWrite(ledPin, LOW);
  changeGateConf(1);
  Serial.println("GET OUT. NOW");
  while(!infra1) {
    Serial.println("GET OUT. NOW");
    alarm(true);
    //delay(150);
  }
  while(infra1);
  alarm(false);
  
}
  
void displaySensors()
{
  // read the input on analog pin 0:
  int sensorValue = analogRead(A0);
  int sensorValue2 = analogRead(A1);
  int but1Value = analogRead(but1);
  int but2Value = analogRead(but2);
  int infra1Value = analogRead(A4);
  int infra2Value = analogRead(A5);
  
  // print out the value you read:
  /*Serial.print("A0: ");
  Serial.println(sensorValue);
  Serial.print("A1: ");
  Serial.println(sensorValue2);
  Serial.print("but 1: ");
  Serial.println(but1Value);
  Serial.print("but 2: ");
  Serial.println(but2Value);*/
  if(infra1Value > 550) {
    Serial.print("Infra 1: ");
    Serial.println(infra1Value);
  }
  if(infra2Value > 500) {
    Serial.print("Infra 2: ");
    Serial.println(infra2Value);
  }
}
  


void loop() 
{ 
  
  displaySensors();

  //infra1!
  if(infra1 && gateConf == 1 && !userIn) {
    userIn = true;
    Serial.print("userIn: ");
    Serial.println(userIn);
    gateConf = 0;
    changeGateConf(gateConf);
    startTime = millis();
  }
  
  if(infra2 && gateConf == 2) {
    gateConf = 1;
    userIn = false;
    digitalWrite(ledPin, LOW);
    changeGateConf(gateConf);
  }
  
  if(gateConf == 0 || gateConf == 2 || (gateConf == 1 && userLeaving)) {
    if((millis() - startTime) <= SAS_TIMER) {
      if(infra1) {
        //User is leaving, but the timer is still running. We don't  want him to sta
        userLeaving = 1;
        gateConf = 1;
        changeGateConf(gateConf);
      }
      else if(!infra1) {
        //User left by gate 1.
        userLeaving = false;
      }
      if(cardIn) {
        if(processCard()) {
          digitalWrite(ledPin, HIGH);
          gateConf = 2;
          changeGateConf(gateConf);
        }
        else
          digitalWrite(ledPin, LOW);
      }
      else
        digitalWrite(ledPin, LOW);
    }
    else {
      Serial.print("startTime = ");
      Serial.println(startTime);
      Serial.print("current time = ");
      Serial.println(millis());
      eject();
      userIn = false;
      userLeaving = false;
    }
      
  }
      

  delay(50);        // delay in between reads for stability
} 

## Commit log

2014-05-12 Update model.
    We do not count the users inside the sas. When one user enters the sas, the first door closes. It can be reopened either by standing before the first infrared, or by being ejected because of the time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
    Fat people not allowed.
2014-05-19 Update model.
    Removes timer y.
    Removes branches to generalize to model.é
2014-06-11 Corrects the problem when the user is ejected from the SAS.
    While the user is in front of infra1, do nothing. This waits for the user to leave the scope of infra1 and avoid the problem of leaving/re-entering when infra1 is triggered consequently.
    [goatv2.ino]
2014-06-11 Montage elec.
    [goat.fzz, goat2.fzz]
2014-06-18 Lien physique and shit... done.
    [goat2 2.fzz]
